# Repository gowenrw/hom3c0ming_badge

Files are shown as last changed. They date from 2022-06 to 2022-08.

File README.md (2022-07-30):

# hom3c0ming_badge

This is a DEFCON Indie badge created for D3FC0N HOM3C0MING a.k.a. DC30.

This is where all the files for the hom3c0ming Badge will be stored.

This includes code and art and cad and fab files.  All the things.

## File Structure

This is the file structure of this repository

* [/](/README.md) - YOU ARE HERE
* [/3D/](./3D/) - 3D print artifacts related to this project
* [/art/](./art/) - Artwork and other graphics created by this project
  * /art/inspiration/ - Art and graphics pulled from other sources used as inspiration for this project
* [/code/](./code/) - All project related Code / Firmware
  * /code/corsage/ - Code for the Raspberry Pi Pico on the corsage PCB
  * /code/firmware/ - CircuitPython firmware used by this project
* [/docs/](./docs/) - Documentation created by this project including web pages
* [/eda/](./eda/) - Electronic Design Automation files (i.e. KiCad)
  * /eda/hom3c0ming_boutonniere/ - KiCad project folder for the boutonniere PCB
  * /eda/hom3c0ming_corsage/ - KiCad project folder for the corsage PCB
* [/reference_parts/](./reference_parts/) - Documentation pulled from other sources related to components
* [./README.md](/README.md) - This File
* [./LICENSE](/LICENSE) - Currently set to MIT

Note: the reference_parts directory is a link to a submodule repository.
To add it use the following cmd after cloning this:
```
git submodule add https://github.com/gowenrw/reference_parts reference_parts
```
This will make a link to the current commit of that repo.
To update it to a newer commit after its been added use this cmd:
```
git submodule update --recursive
```

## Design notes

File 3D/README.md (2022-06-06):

# 3D

This is where all the 3D print artifacts for this project are located.

This project uses translucent 3D printed LED covers.

The LED covers are designed to be screwed to the PCB using M2 self threading screws (i.e.,  wood/machine screws, not bolts) via designated drill holes in the PCB.

## 3D STL Files

There is a 3D Model I created for the Rose shaped LED cover.
This has been provided in several STL files for printing (quantity differences supporting different print bed sizes or time constraints).

Here are the STL files:

*  [Rose_LED_Cover_w_Leaves.stl](Rose_LED_Cover_w_Leaves.stl)
*  [Rose_LED_Cover_w_Leaves_x15.stl](Rose_LED_Cover_w_Leaves_x15.stl)
*  [Rose_LED_Cover_w_Leaves_x20.stl](Rose_LED_Cover_w_Leaves_x20.stl)
*  [Rose_LED_Cover_w_Leaves_x40.stl](Rose_LED_Cover_w_Leaves_x40.stl)

## My Setup

I own a FlashForge Adventurer 3 printer which I slice prints for using FlashPrint, and a Creality Ender 3V2 which I slice prints for using Cura.

The directory FlashForgeAdv3 contains my FlashPrint project files, printer configuration profiles, and gcode for various STL files above.

The directory Ender3V2_Cura contains my Cura project files, printer configuration profiles, and gcode for various STL files above.

## Custom profile settings and material for this project

The material I am using for this project is the [Amazon Basics PLA 3D Printer Filament, 1.75mm, Translucent, 1 kg Spool](https://www.amazon.com/dp/B07SZLZG3L).

As you are setting up your machine to print these parts here are some notes about what I changed from my default print setting and why:

*  Layer height 0.16mm - Setting just a bit better than standard 0.2mm layers makes a big difference in the quality without that much added time.
*  Raft with 9mm-15mm margin - Given how small the surface area of the bottom layer is compared to the height, a wide solid raft was needed to prevent tip overs during printing

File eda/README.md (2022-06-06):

# Electronic Design Automation

This is where all the Electronic Design Automation files for the PCB(s) will be stored.
The EDA used is KiCad 5.x unless otherwise specified.

The KiCad projects have been configured to use local libraries for long term sustainability per the best practices listed [HERE](https://hackaday.com/2017/05/18/kicad-best-practises-library-management/) and elsewhere.

## File Structure

This is the file structure of this repository

* [/](/README.md) - Home
* [/eda](/eda/) - YOU ARE HERE
  * /eda/<eda_project>/ - KiCad project folder for the named project PCB(s)
    * ./3d_models/ - This directory contains footprint 3d model files
    * ./gerber/ - This directory contains gerber formatted files for manufacturing
    * ./lib_fp/ - This directory contains footprint module directories
    * ./lib_sh/ - This directory contains schematic library files
    * ./snapshots/ - This directory contains prints of schematic / cad files and images of preview / final product

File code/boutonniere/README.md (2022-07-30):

# Code

Code folder for the PCB.

Note: The boutonniere mini badge does not have a microcontroller and thus will have no code.

Keeping this directory in case I change my mind about that.

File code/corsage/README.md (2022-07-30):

# Code

Code folder for the PCB

Each directory here will contain the CircuitPython code and libraries to run the given program on the badge.

To change the code running on the badge simply connect the Pico via USB to a computer and replace the .py files and /lib files on the mass storage device with the ones provided in the chosen directory.

Note: If you upgrade the CircuitPython version you will need to download the version specific version of the library files to match the version you are running for any external libraries you are calling in your code (like neopixel.mpy).

You can download CircuitPython library files here:

[CircuitPython Library File Downloads](https://circuitpython.org/libraries)

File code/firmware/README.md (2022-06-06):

# Firmware

Firmware used by the badges

## Adafruit CircuitPython

I decided to use the Adafruit CircuitPython firmware on the Raspberry Pi Pico for the corsage badge.

Nothing against Raspberry MicroPython, I just like CircuitPython more.

The Raspberry Pi Pico boards that will be provided with the badges will be preloaded with a specific Adafruit CircuitPython version

Currently using version 7.2.5 but might change as we get closer to badge release date.

In case you need to reload your board or are using a different Pico than provided I have included the uf2 firmware file I used here so you can use the same version I did.

To load the new firmware follow these simple steps:

*  Push and hold the BOOTSEL button and plug your Pico into the USB port of your Raspberry Pi or other computer.
*  Release the BOOTSEL button after your Pico is connected.
*  It will mount as a Mass Storage Device called RPI-RP2
*  Drag and drop the CircuitPython UF2 file onto the RPI-RP2 volume.
*  Your Pico will reboot. You are now running CircuitPython.

If you wish to try a different version than I used then you can find all the CircuitPython for Pico downloads here:

[CircuitPython for Pico Downloads](https://circuitpython.org/board/raspberry_pi_pico/)

Note: If you upgrade the CircuitPython version you will need to download the version specific version of the library files to match the version you are running for any external libraries you are calling in your code (like neopixel.mpy).

You can download CircuitPython library files here:

[CircuitPython Library File Downloads](https://circuitpython.org/libraries)

For more information about the Raspberry Pi Pico including data sheets and downloads like their MicroPython firmware go to this page:

[Raspberry Pi Microcontrollers Documentation](https://www.raspberrypi.com/documentation/microcontrollers/)

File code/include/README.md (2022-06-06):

# Code Includes

Common code includes used by the other code folders

Since CircuitPython was chosen as the code base for the badge there will not be any include files.

Keeping this directory in case I change my mind about code base.

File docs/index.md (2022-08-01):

---
layout: default
---

[Home](/) - [Corsage](corsage-assembly.md) - [Boutonniere](boutonniere-assembly.md)

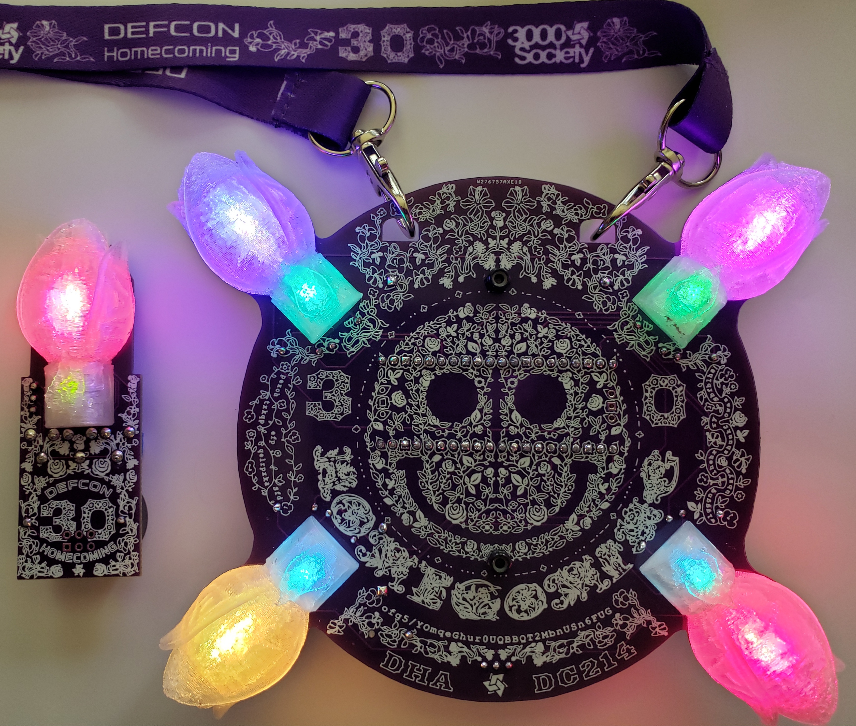
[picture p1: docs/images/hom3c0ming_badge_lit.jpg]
hom3c0ming badge


# hom3c0ming badge

Welcome to the hom3c0ming badge website/repository.

This is where you will find all the details and files and instructions related to my DC30 hom3c0ming badge kit.

The idea for this badge came from the DEFCON 30th anniversary theme: "Hacker Homecoming".
Thinking of the high school homecoming dances of my youth I immediately thought of flowers.

This kit is made up of two parts: A Corsage and a Boutonniere.
The corsage is the traditional badge shape/size with a lanyard and the boutonniere is a small pin-on or SAO attached add on.

I wanted to focus more on the art then features.  That being said, using the Raspberry Pi Pico opens up many hackable opportunities for this badge.
There are plenty of badges out there that do all the things.  I wanted this one to have all the looks.  And I think I have achieved that goal.

To focus on the art I spent literally hundreds of hours perfecting what is the most detailed silk layer I have ever attempted before.  I also included a 3D print element in the form of flowers that are LED diffusers which attach to the badge.

Regarding this being a kit that you need to assemble, this was a choice made due to popular demand.  My previous few badges were fully assembled and were big hits, but many people asked for kit versions and expressed their love of the DIY badge kit.  I think that building a badge from a kit gets a person invested in that badge and raises their appreciation for it.  So, the decision was made to make this a kit.

I hope that everyone who gets one of these badge kits enjoys it.  It was made with love for everyone in the community to enjoy.  And as with all my badges, it is all open hardware/software with all files provided in this repository.  So, if you didn't have a chance to get one of these kits at the con you can always make your own.

-- [@alt_bier](https://twitter.com/alt_bier)  - [My Contact Info](https://gowen.net/about)

---

# Details

Assembly Instructions for the Corsage can be found here: [Corsage](corsage-assembly.md)

Assembly Instructions for the Boutonniere can be found here: [Boutonniere](boutonniere-assembly.md)

Assembly walkthrough video can be found here:
[Hom3c0ming Badge Assembly](https://www.youtube.com/watch?v=d4AU95CxsSo&ab_channel=alt_bier_hacker)

More badge details to be added soon.

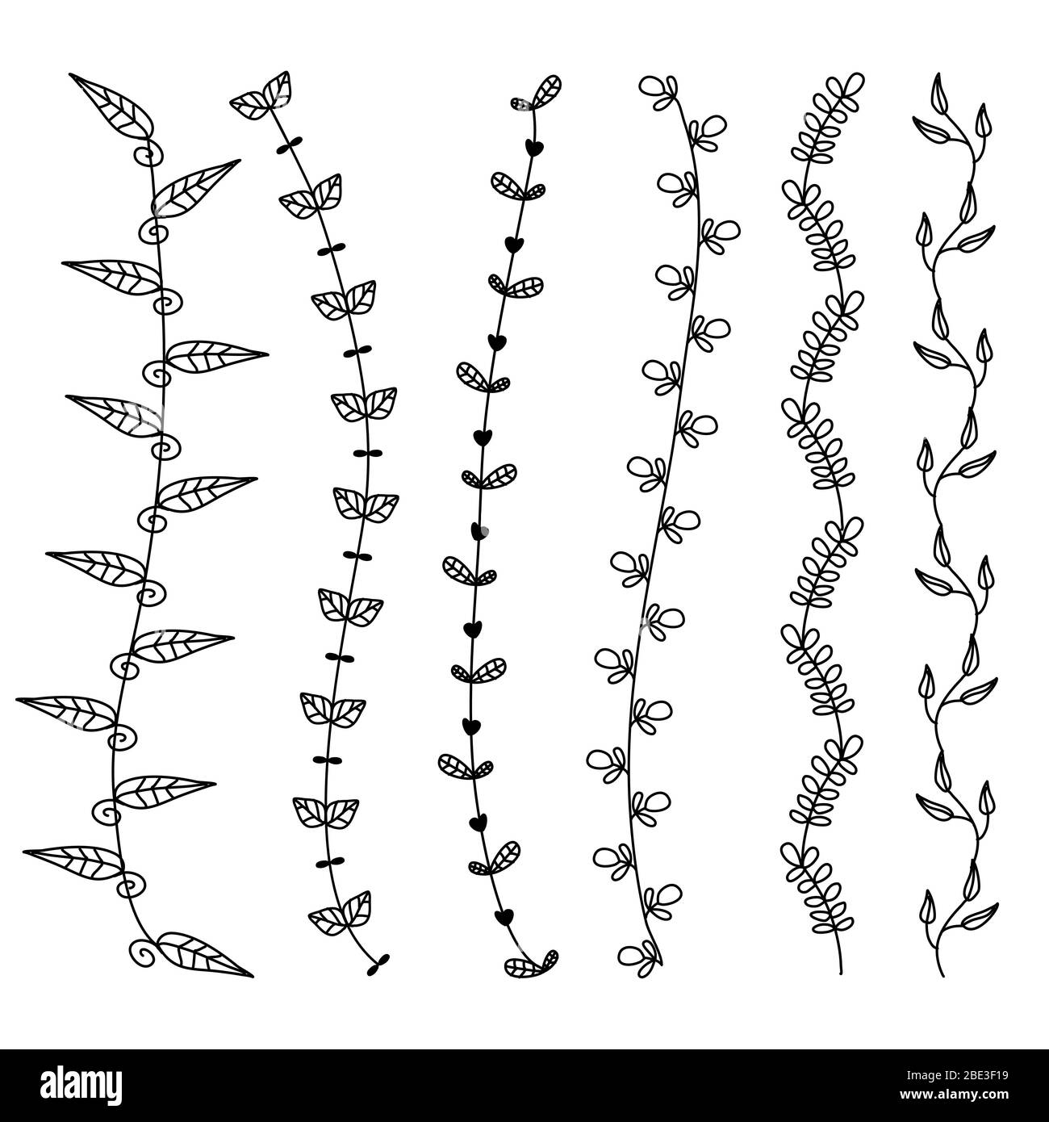
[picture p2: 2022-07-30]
art/inspiration/flower-vine-leaves-hand-drawn-doodle-vector-line-border-set-and-design-element-2BE3F19.jpg

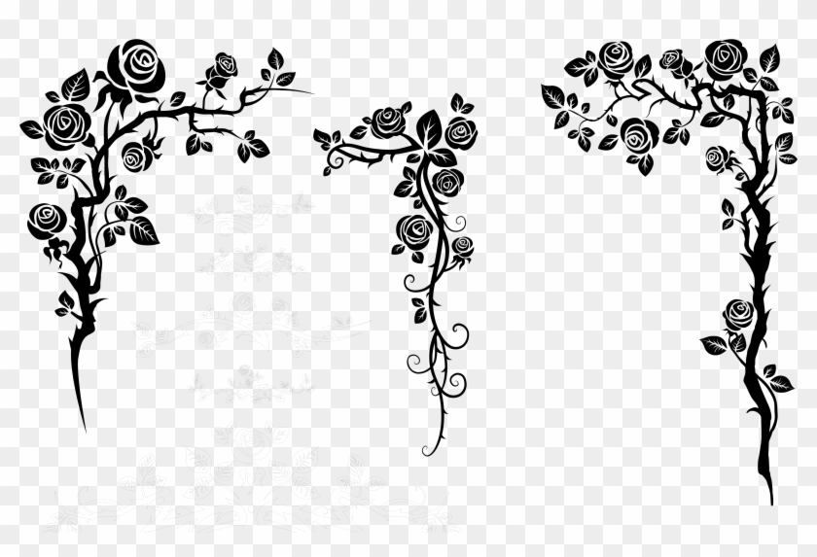
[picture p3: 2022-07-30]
art/inspiration/183-1831658_flower-vine-silhouette-nature-border-design-drawing-hd.png

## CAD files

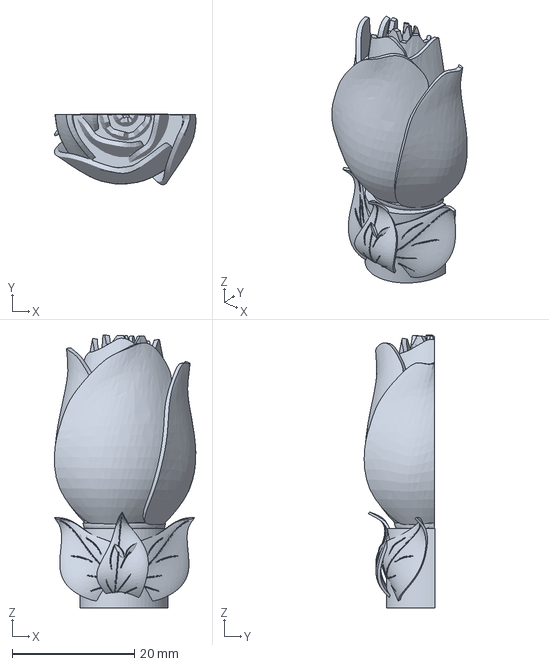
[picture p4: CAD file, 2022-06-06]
3D/Ender3V2_Cura/Rose_LED_Cover_w_Leaves.3mf
23.2 x 11.6 x 44.7 mm

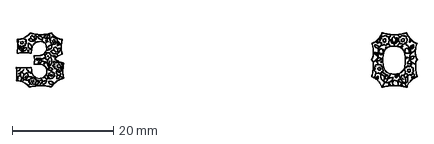
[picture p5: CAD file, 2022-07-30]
art/Corsage_front-2-Thirty.dxf
79.4 x 10.8 mm

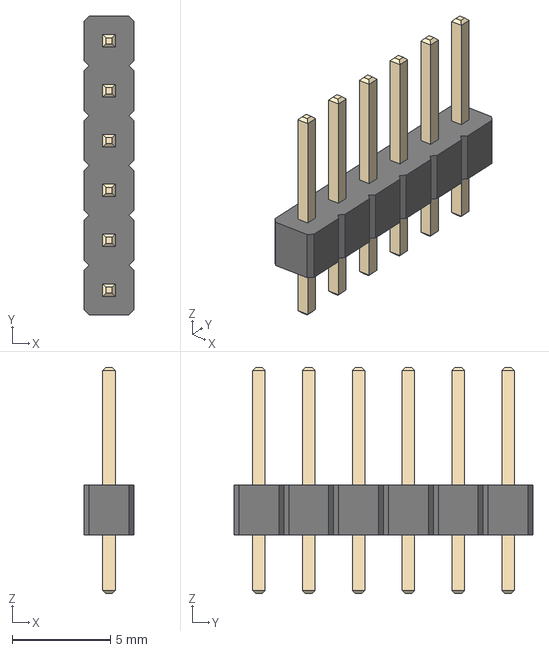
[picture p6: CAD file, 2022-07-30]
eda/hom3c0ming_boutonniere/3d_models/PinHeader_1x06_P2.54mm_Vertical.step
2.54 x 15.2 x 11.5 mm

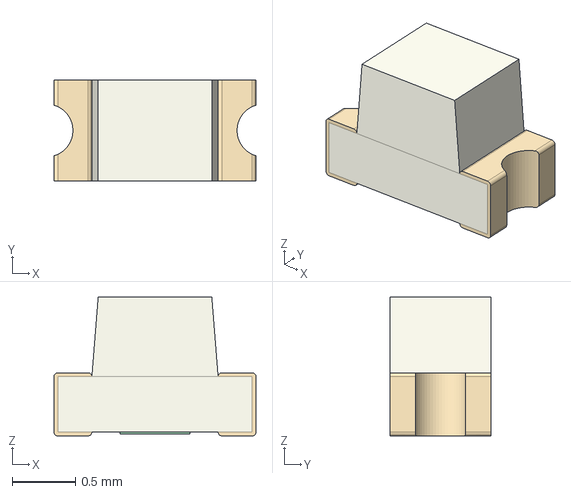
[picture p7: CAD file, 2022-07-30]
eda/hom3c0ming_corsage/3d_models/LED_0603_1608Metric_Castellated.step
1.60 x 0.8 x 1.10 mm

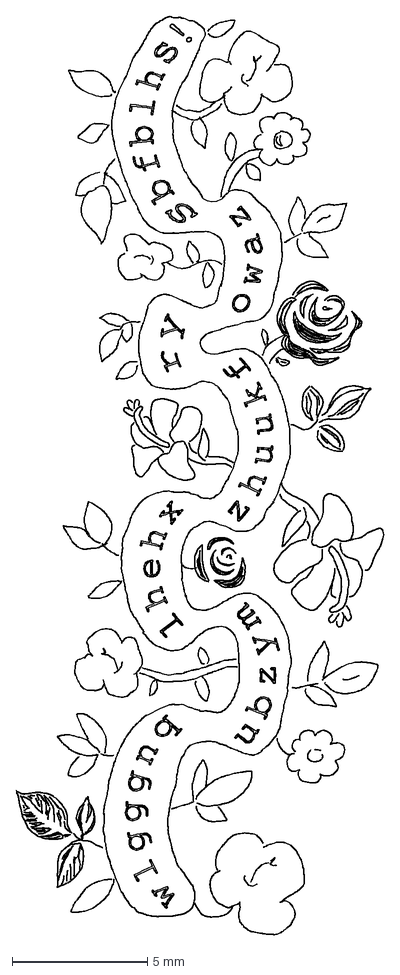
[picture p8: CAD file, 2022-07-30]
art/Corsage_front-4-FlowersRightSide.dxf
13.6 x 33.9 mm

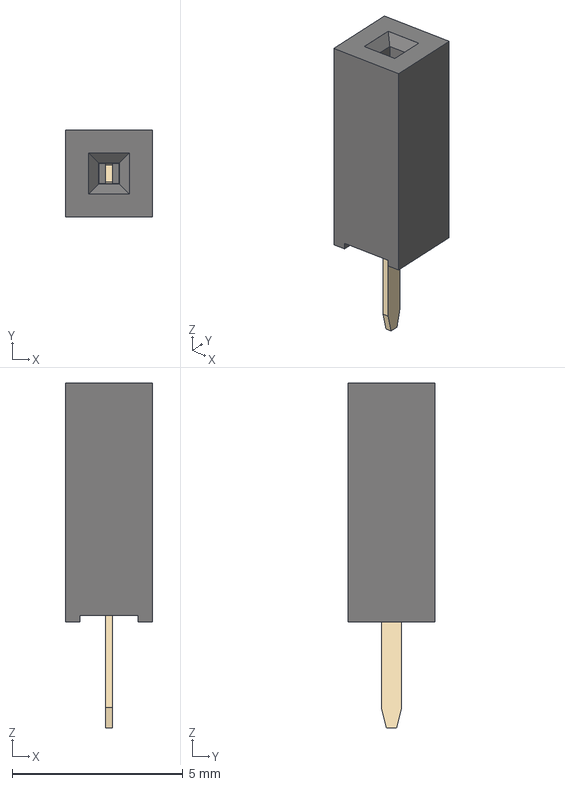
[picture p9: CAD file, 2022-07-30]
eda/hom3c0ming_boutonniere/3d_models/PinSocket_1x01_P2.54mm_Vertical.step
2.54 x 2.54 x 10.1 mm

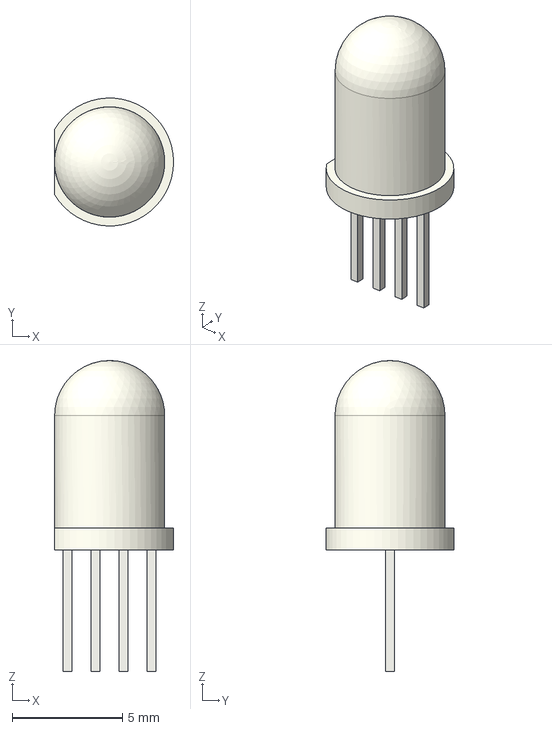
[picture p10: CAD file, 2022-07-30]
eda/hom3c0ming_corsage/3d_models/LED_D5.0mm-4_RGB_Neo.step
5.40 x 5.79 x 14.1 mm

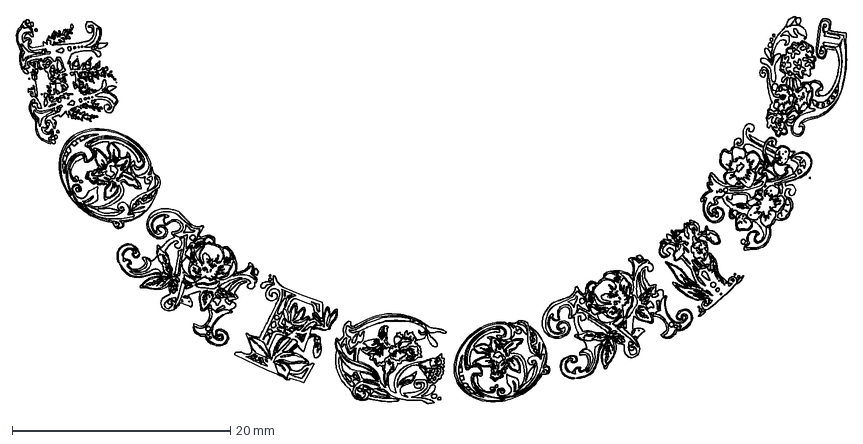
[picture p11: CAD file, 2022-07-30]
art/Corsage_front-2-HomeComing.dxf
76.0 x 35.5 mm

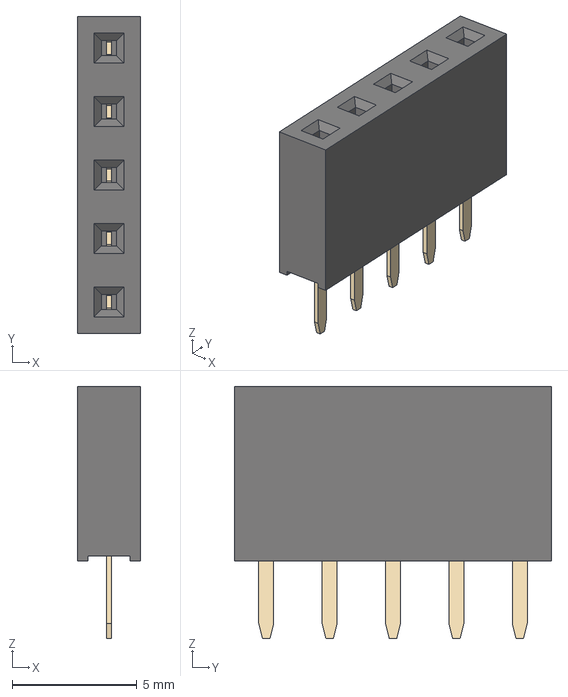
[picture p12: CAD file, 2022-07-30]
eda/hom3c0ming_boutonniere/3d_models/PinSocket_1x05_P2.54mm_Vertical.step
2.54 x 12.7 x 10.1 mm

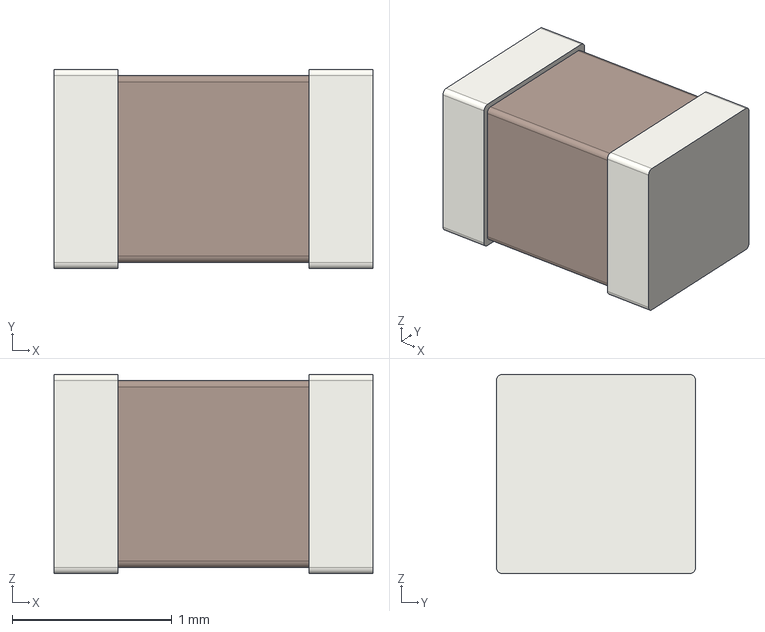
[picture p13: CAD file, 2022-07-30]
eda/hom3c0ming_corsage/3d_models/C_0805_2012Metric.step
2.00 x 1.25 x 1.25 mm

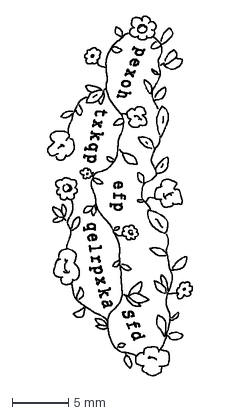
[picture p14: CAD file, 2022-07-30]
art/Corsage_front-4-FlowersLeftSide.dxf
12.9 x 31.9 mm

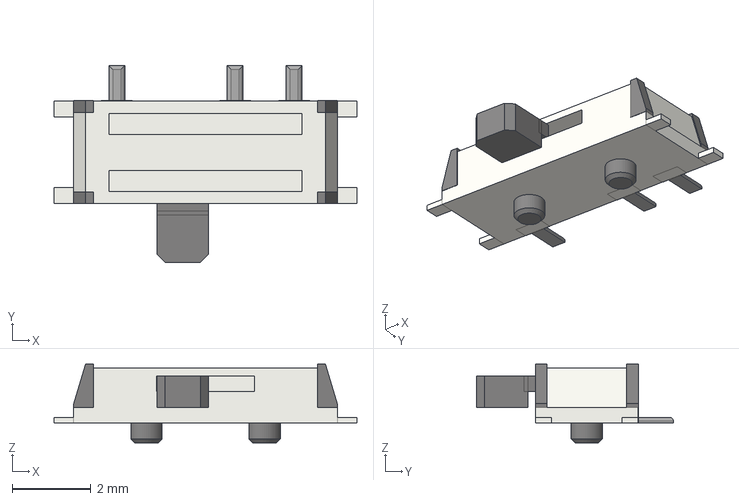
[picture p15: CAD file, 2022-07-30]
eda/hom3c0ming_boutonniere/3d_models/SW_SPDT_PCM12.step
7.70 x 5.00 x 2.00 mm

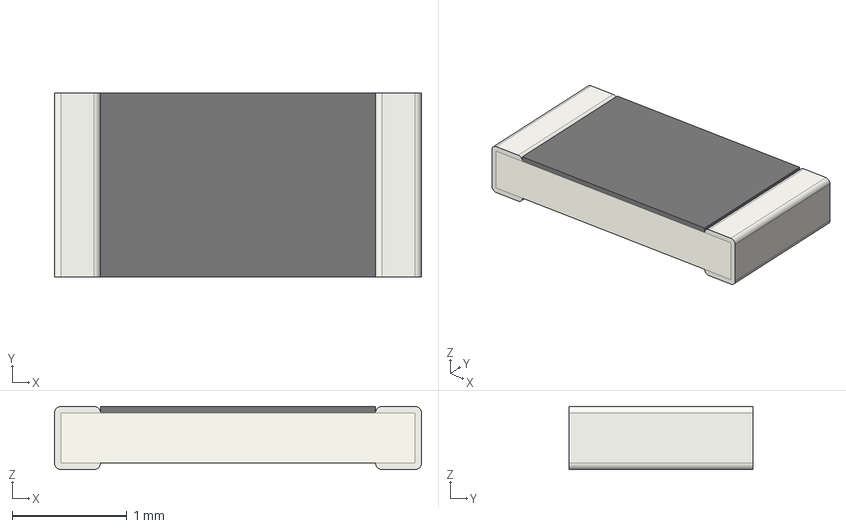
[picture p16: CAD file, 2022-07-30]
eda/hom3c0ming_corsage/3d_models/R_1206_3216Metric.step
3.20 x 1.60 x 0.55 mm

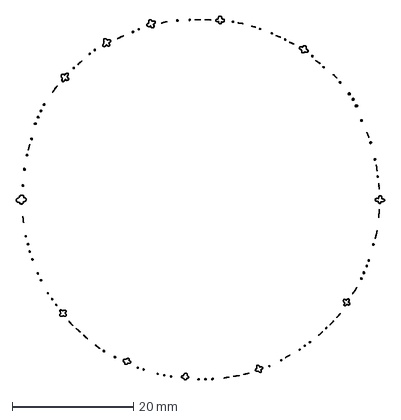
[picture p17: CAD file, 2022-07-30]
art/Corsage_front-3-MLine.dxf
60.7 x 59.9 mm

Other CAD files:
3D/Rose_LED_Cover_w_Leaves.stl
eda/hom3c0ming_boutonniere/3d_models/PinHeader_1x08_P2.54mm_Horizontal.step
eda/hom3c0ming_corsage/3d_models/C_Rect_L4.6mm_W2.0mm_P2.50mm_MKS02_FKP02.step
art/Corsage_front-5-FlowersBottom.dxf
eda/hom3c0ming_boutonniere/3d_models/BatteryHolder_2466_1xAAA.step
eda/hom3c0ming_boutonniere/3d_models/BatteryHolder_2468_2xAAA.step
eda/hom3c0ming_boutonniere/3d_models/Battery_Holder_3xAAA_Simple.step
eda/hom3c0ming_boutonniere/3d_models/Battery_Holder_CR2032_BS-2-1.stp
eda/hom3c0ming_boutonniere/3d_models/CP_Radial_D5.0mm_P2.00mm.step
eda/hom3c0ming_boutonniere/3d_models/CP_Radial_D6.3mm_P2.50mm.step
eda/hom3c0ming_boutonniere/3d_models/C_0603_1608Metric.step
eda/hom3c0ming_boutonniere/3d_models/C_1206_3216Metric.step
eda/hom3c0ming_boutonniere/3d_models/C_Disc_D3.0mm_W2.0mm_P2.50mm.step
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

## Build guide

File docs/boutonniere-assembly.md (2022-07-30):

---
layout: default
---

[Home](/) - [Corsage](corsage-assembly.md) - [Boutonniere](boutonniere-assembly.md)

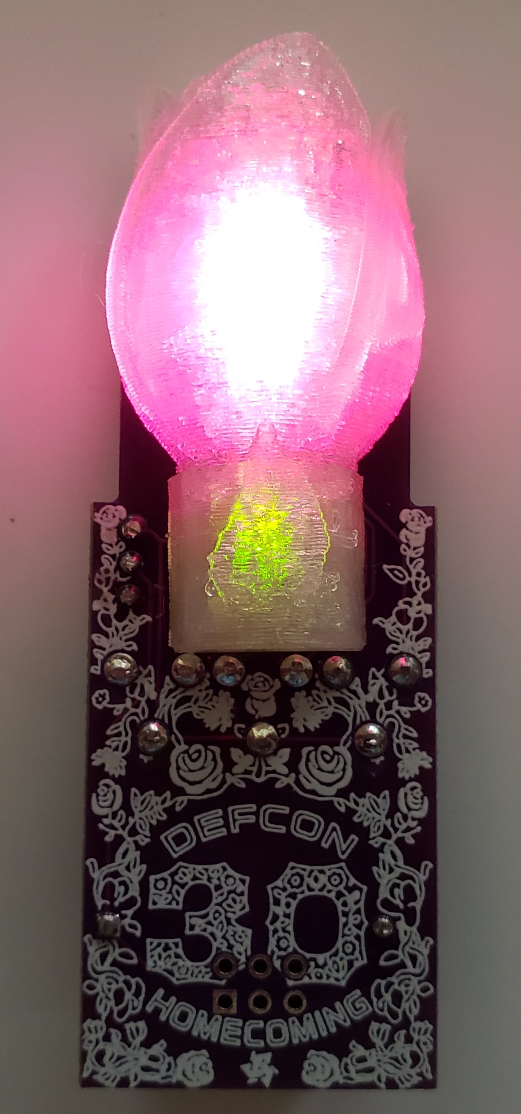
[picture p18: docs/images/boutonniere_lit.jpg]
Boutonniere Image


# Boutonniere Assembly Instructions

Here are the assembly instructions I put together for the Boutonniere hom3c0ming badge add on.

## Component List

This is the list of components that you should have available for the assembly.

*  Boutonniere Kit Bag
    *  1x PCB
    *  1x CR2032 Battery Holder
    *  1x CR2032 Battery
    *  1x 3D Printed Flower LED Diffusers
    *  Boutonniere Small Component Bag Containing:
        *  1x SS12D00 3-Pin SPDT Switch
        *  1x 100 Ohm Resistor
        *  1x 220 Ohm Resistor
        *  3x 47 Ohm Resistors
        *  3x 0-10K Ohm 3-Pin Variable Resistors
        *  1x RGB Common Cathode 5mm 4-Pin LED
        *  1x Green 3mm 2-Pin LED
        *  1x Broach Clip 20mm
        *  Small Screw Hardware Bag Containing:
            *  2x M2x6 Phillips Pan Head Self Tapping Screws
            *  2x M2x5 Phillips Pan Head Screws
            *  2x M2 Hex Nuts

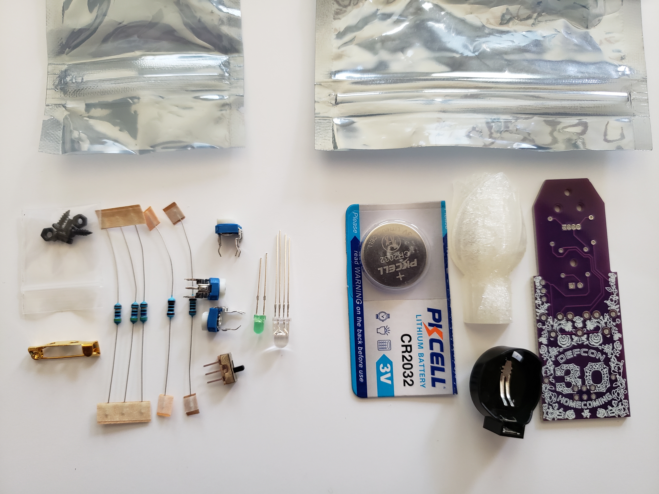
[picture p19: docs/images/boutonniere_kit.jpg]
Boutonniere Kit


## Soldering Steps

These are the assembly steps that require soldering.
I have presented them in the order I recommend they be implemented for best results.

Before soldering you will need to make a choice between the 100 ohm and 220 ohm resistors for use with the 3mm green LED.  The lower resistance will make the green LED slightly brighter.  I personally prefer the look with the 220 ohm resistor.

*  Solder the 3x 47 Ohm Resistors to the back side of the PCB using the THT holes labeled R1, R2, R3.
    *  This component should be placed with its body on the back side of the PCB and its pins sticking through to the front side of the PCB.
    *  Bending the component pins to an angle after insertion into the PCB will keep it in place when flipping over the PCB to solder.
    *  The component pins should be soldered on the front side of the PCB.
    *  The component pins should be cut as flush to the PCB as the solder joint allows (don't cut the solder joint!).

*  Solder either the 100 ohm OR the 220 ohm Resistor to the back side of the PCB using the THT holes labeled R4.
    *  This component should be placed with its body on the back side of the PCB and its pins sticking through to the front side of the PCB.
    *  Bending the component pins to an angle after insertion into the PCB will keep it in place when flipping over the PCB to solder.
    *  The component pins should be soldered on the front side of the PCB.
    *  The component pins should be cut as flush to the PCB as the solder joint allows (don't cut the solder joint!).

*  Solder the 1x RGB Common Cathode 5mm 4-Pin LED to the front side of the PCB using the THT holes labeled D1.
    *  This component should be placed with its body on the front side of the PCB and its pins sticking through to the back side of the PCB.
    *  Take care to ensure that the component is inserted with the correct alignment by comparing the flat side of the LED body to the indicator lines on the PCB.
    *  This component should be fully inserted in the PCB as far as it can go (i.e., past the stop notches on the pins)
    *  Take care to ensure the component body stays flush to the PCB at 90 degrees when soldering (which should not be much of an issue if inserted fully)
    *  The component pins should be soldered on the back side of the PCB.
    *  The component pins should be cut as flush to the PCB as the solder joint allows (don't cut the solder joint!).

*  Solder the 1x Green 3mm 2-Pin LED to the front side of the PCB using the THT holes labeled D2.
    *  This component should be placed with its body on the front side of the PCB and its pins sticking through to the back side of the PCB.
    *  Take care to ensure that the component is inserted with the correct alignment by comparing the flat side of the LED body to the indicator lines on the PCB.
    *  This component should be fully inserted in the PCB as far as it can go (i.e., past the stop notches on the pins)
    *  Take care to ensure the component body stays flush to the PCB at 90 degrees when soldering (which should not be much of an issue if inserted fully)
    *  The component pins should be soldered on the back side of the PCB.
    *  The component pins should be cut as flush to the PCB as the solder joint allows (don't cut the solder joint!).

*  Solder the 3-Pin Switch to the back side of the PCB using the THT holes labeled ON / OFF.
    *  This component should be placed with its body on the back side of the PCB and its pins sticking through to the front side of the PCB.
    *  Take care to ensure the component body stays flush to the PCB at 90 degrees when soldering
    *  The component pins should be soldered on the front side of the PCB.
    *  The component pins should be cut as flush to the PCB as the solder joint allows (don't cut the solder joint!).  

*  Solder the 3x 0-10K Ohm 3-Pin Variable Resistors to the back side of the PCB using the THT holes labeled RV1, RV2, RV3.
    *  This component should be placed with its body on the back side of the PCB and its pins sticking through to the front side of the PCB.
    *  Take care to ensure that the component is inserted with the correct alignment by using the indicator lines on the PCB.
    *  The component pins should be soldered on the front side of the PCB.
    *  The component pins should be cut as flush to the PCB as the solder joint allows (don't cut the solder joint!).
    *  Pro Tip: Inserting all of these components and then soldering them all allows for faster assembly time

*  Solder the CR2032 Battery Holder to the back side of the PCB in the area indicated on the PCB
    *  This component should be placed with its body on the back side of the PCB and its pins sticking through to the front side of the PCB.
    *  Take care to ensure that the component is inserted with the correct alignment by using the indicator lines on the PCB.
    *  The component pins should be soldered on the front side of the PCB.
    *  The component pins should be cut as flush to the PCB as the solder joint allows (don't cut the solder joint!).
    * Note: If you plan on soldering an SAO connector (not provided in the kit) to this badge then you must NOT solder this battery connector on as this is an either or choice.

## Additional Assembly Steps

These are the additional assembly steps that do not require soldering.
I have presented them in the order I recommend they be implemented for best results.

*  Attach the Broach Clip to the back of the PCB using the M2 fasteners
    *  Unclip the Broach Clip pin and move the pin out of the way exposing the attachment holes.
    *  Hold the Broach Clip against the back of the PCB in its designated location as marked on the PCB making sure the attachment holes line up with the drill holes on the PCB.
    *  Insert an M2x2 Phillips Pan Head Screw through one of the Broach Clip attachment holes into the back of the PCB
    *  Hold the M2 screw in place using a small Phillips head screwdriver
    *  While holding the screw and Broach Clip in place attach an M2 Hex Nut to the end of the screw on the front of the PCB and use fingers to rotate the nut until it is close to the PCB but still loose
    *  Insert an M2x2 Phillips Pan Head Screw through the other Broach Clip attachment hole into the back of the PCB
    *  Hold the M2 screw in place using a small Phillips head screwdriver
    *  While holding the screw and Broach Clip in place attach an M2 Hex Nut to the end of the screw on the front of the PCB and use fingers to rotate the nut until it is close to the PCB but still loose
    *  While holding the hex nuts in place with a tool or fingers, tighten each of these fasteners with a small Phillips head screwdriver
    *  Close the pin on the Broach Clip

*  Attach the 3D Printed Flower LED Diffuser to the front of the PCB using the M2 fasteners
    *  Insert an M2x6 Phillips Pan Head Self Tapping Screw into the back of the PCB into the bottom of the two PCB holes for a flower
    *  Hold the M2 screw in place using a small Phillips head screwdriver
    *  Align the flower middle screw hole over the M2 screw tip sticking through the PCB
    *  While holding the flower in place in the correct alignment (flower top towards PCB edge) use a small Phillips head screwdriver to tighten this fastener just enough that it has a solid grip on the flower but the flower can still move around - DO NOT FULLY TIGHTEN YET
    *  Insert an M2x6 Phillips Pan Head Self Tapping Screw into the back of the PCB into the top (PCB edge) of the two PCB holes for a flower
    *  Hold the M2 screw in place using a small Phillips head screwdriver
    *  Align the flower top screw hole over the M2 screw tip sticking through the PCB
    *  While holding the flower in place in the correct alignment use a small Phillips head screwdriver to fully tighten this fastener in place
    *  Use a small Phillips head screwdriver to fully tighten the bottom screw in place which was left loose in the previous step

## Battery, Pin, and Wear FTW

*  Insert the CR2032 battery into the battery holder with the Positive (+) side up and visible.
    *  Take care to insert using proper polarity or the badge will not power on.

*  Attach the badge to clothing or items by pinning in place using the Broach Clip.

*  With the battery inserted and the badge attached, the ON/OFF switch will control your #Badgelife awesomeness factor

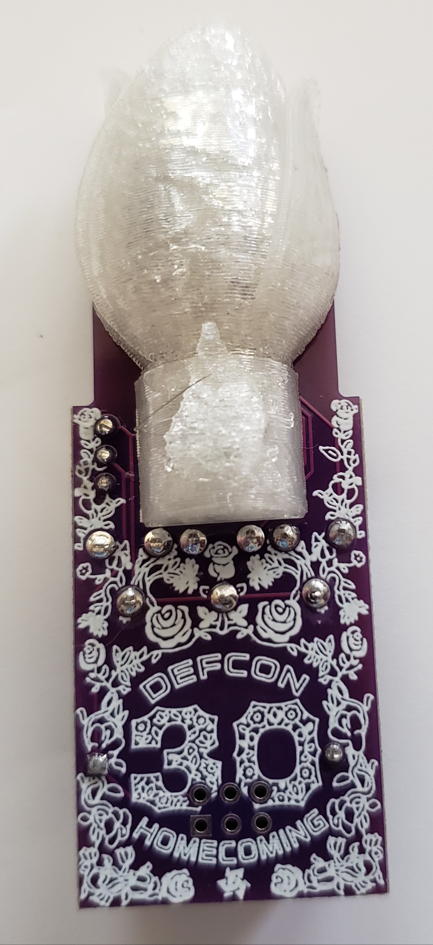
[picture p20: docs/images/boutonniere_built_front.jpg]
Boutonniere Front


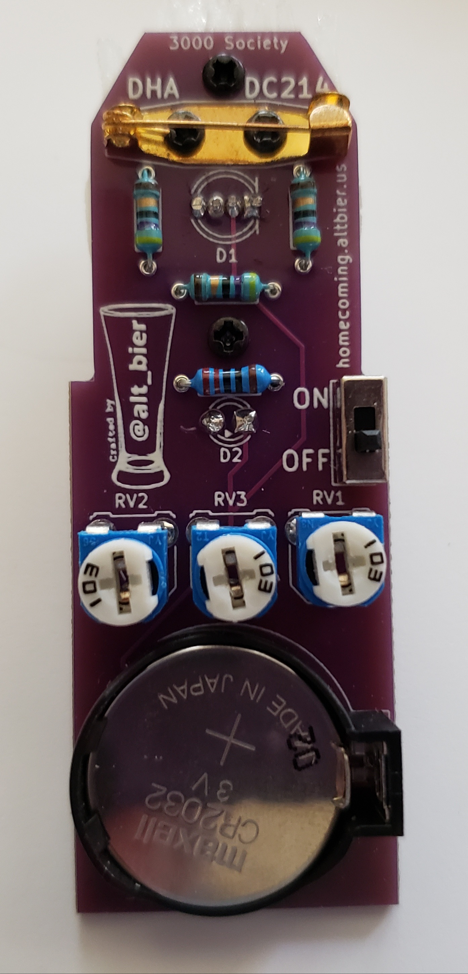
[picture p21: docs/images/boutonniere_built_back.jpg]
Boutonniere Back


-- [@alt_bier](https://twitter.com/alt_bier)  - [My Contact Info](https://gowen.net/about)

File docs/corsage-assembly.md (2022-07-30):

---
layout: default
---

[Home](/) - [Corsage](corsage-assembly.md) - [Boutonniere](boutonniere-assembly.md)

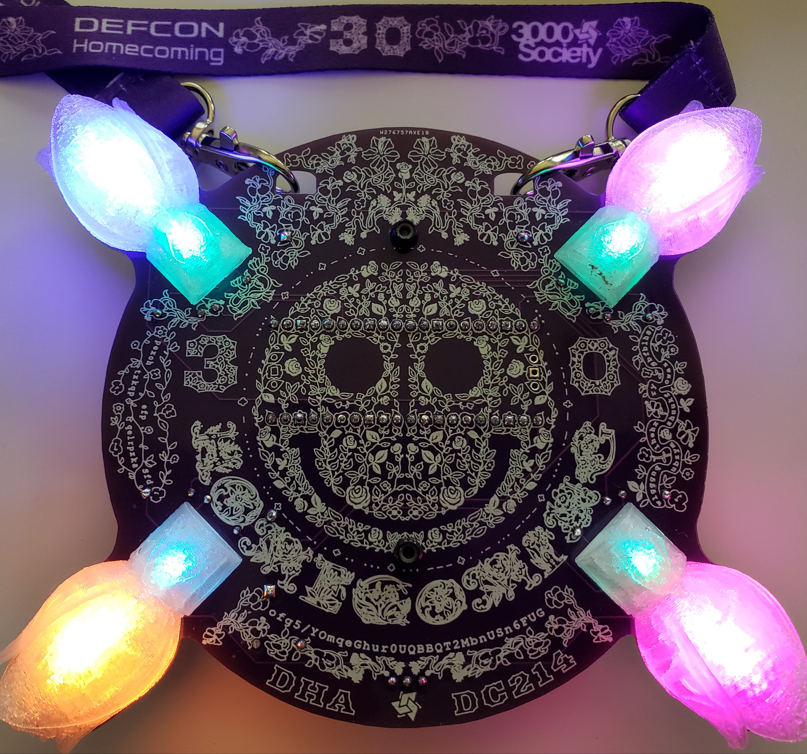
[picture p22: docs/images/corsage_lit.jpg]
Corsage Image


# Corsage Assembly Instructions

Here are the assembly instructions I put together for the Corsage hom3c0ming badge.

## Component List

This is the list of components that you should have available for the assembly.

*  Main Kit Bag Containing:
    *  1x Sticker (Not Required for Corsage Assembly)
    *  1x PCB
    *  1x Lanyand
    *  3x AAA Batteries
    *  Boutonniere Kit Bag (Not Required for Corsage Assembly)
    *  Corsage Large Component Bag Containing:
        *  1x Raspberry Pi Pico
        *  1x Header Pin Breakaway Strip with 1x40 Pins  
        *  1x Single AAA Battery Holder with THT Pins
        *  1x Dual AAA Battery Holder with THT Pins
        *  4x 3D Printed Flower LED Diffusers
        *  1x Mini Phillips Head Screwdriver
        *  Small Screw Hardware Bag Containing:
            *  8x M2x6 Phillips Pan Head Self Tapping Screws
            *  2x M2.5x6 Phillips Flat Head Screws
            *  2x M2.5 Nylock Hex Locking Nuts
  *  Corsage Small Component Bag Containing:
      *  1x CJ3415 SMT PNP MOSFET Transistor
      *  1x SS12D00 3-Pin SPDT Switch
      *  1x 22K Ohm Resistor
      *  12x 470 Ohm Resistors
      *  4x 100nF Ceramic Disc Capacitors
      *  4x WS2812D RPIN 5mm 4-Pin Addressable LEDs
      *  4x Two Color (BG) 3mm 3-Pin LEDs

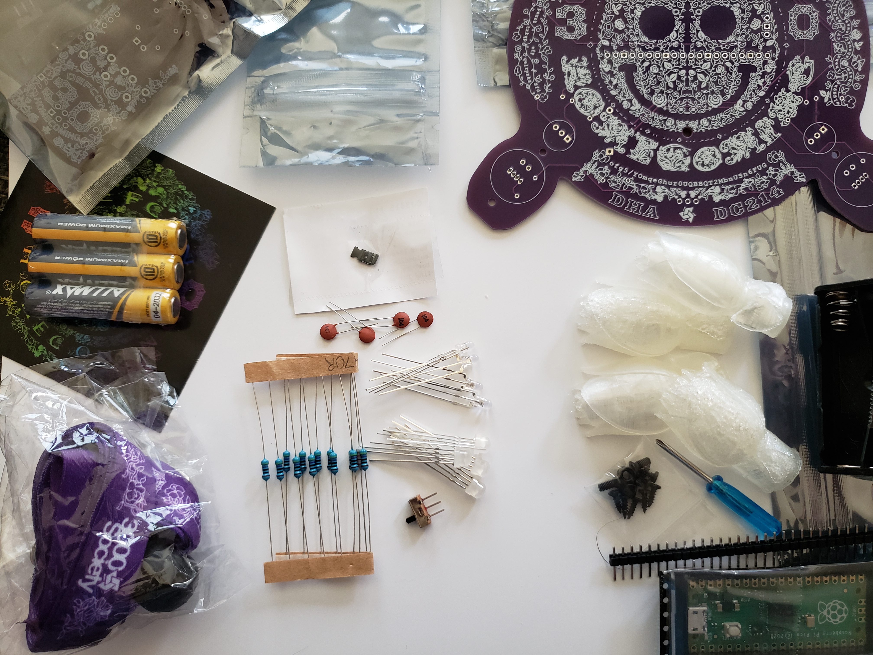
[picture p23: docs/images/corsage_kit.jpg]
Corsage Kit


## Soldering Steps

These are the assembly steps that require soldering.
I have presented them in the order I recommend they be implemented for best results.

### Power Protection Circuit

*  Solder the SMT MOSFET Transistor to the back side of the PCB on the pads labeled Q1.
    *  This is a surface mount component that can be hand soldered to the PCB
    *  The PCB pads for this component are extra wide to assist in hand soldering
    *  Solder the component to the back side of the PCB.
        *  The component will need to be held in place until the first pin is soldered (use a tool not a thumbnail!)

*  Solder the 22K Ohm Resistor to the back side of the PCB using the THT holes labeled R1.
    *  This component should be placed with its body on the back side of the PCB and its pins sticking through to the front side of the PCB.
    *  Bending the component pins to an angle after insertion into the PCB will keep it in place when flipping over the PCB to solder.
    *  The component pins should be soldered on the front side of the PCB.
    *  The component pins should be cut as flush to the PCB as the solder joint allows (don't cut the solder joint!).

*  Solder the 3-Pin Switch to the back side of the PCB using the THT holes labeled ON / OFF.
    *  This component should be placed with its body on the back side of the PCB and its pins sticking through to the front side of the PCB.
    *  Take care to ensure the component body stays flush to the PCB at 90 degrees when soldering
    *  The component pins should be soldered on the front side of the PCB.
    *  The component pins should be cut as flush to the PCB as the solder joint allows (don't cut the solder joint!).  

### Small Back Side Components: Resistors

*  Solder the 12x 470 Ohm Resistors to the back side of the PCB using the THT holes labeled R2, R4, R6, R8, R10, R12, R14, R16, R181, R182, R201, R202.
    *  This component should be placed with its body on the back side of the PCB and its pins sticking through to the front side of the PCB.
    *  Bending the component pins to an angle after insertion into the PCB will keep it in place when flipping over the PCB to solder.
    *  The component pins should be soldered on the front side of the PCB.
    *  The component pins should be cut as flush to the PCB as the solder joint allows (don't cut the solder joint!).
    *  Pro Tip: Inserting all of these components and then soldering them all allows for faster assembly time

### Small Front Side Components: LEDs and Capacitors

*  Solder the 4x Two Color 3mm 3-Pin LEDs to the front side of the PCB using the THT holes labeled D1, D2, D3, D4.
    *  This component should be placed with its body on the front side of the PCB and its pins sticking through to the back side of the PCB.
    *  Take care to ensure that the component is inserted with the correct alignment by comparing the flat side of the LED body to the indicator lines on the PCB.
    *  This component should be fully inserted in the PCB as far as it can go (i.e., past the stop notches on the pins)
    *  Take care to ensure the component body stays flush to the PCB at 90 degrees when soldering (which should not be much of an issue if inserted fully)
    *  The component pins should be soldered on the back side of the PCB.
    *  The component pins should be cut as flush to the PCB as the solder joint allows (don't cut the solder joint!).
    *  Pro Tip: Inserting all of these components and then soldering them all allows for faster assembly time and keeps the PCB level while soldering.

*  Solder the 4x 100nF Ceramic Disc Capacitors to the front side of the PCB using the THT holes labeled C501, C502, C601, C602.
    *  This component should be placed with its body on the front side of the PCB and its pins sticking through to the back side of the PCB.
    *  Bending the component pins to an angle after insertion into the PCB will keep it in place when flipping over the PCB to solder.
    *  The component pins should be soldered on the back side of the PCB.
    *  The component pins should be cut as flush to the PCB as the solder joint allows (don't cut the solder joint!).
    *  Pro Tip: Inserting all of these components and then soldering them all allows for faster assembly time

*  Solder the 4x WS2812D 5mm 4-Pin LEDs to the front side of the PCB using the THT holes labeled D501, D502, D601, D602.
    *  This component should be placed with its body on the front side of the PCB and its pins sticking through to the back side of the PCB.
    *  Take care to ensure that the component is inserted with the correct alignment by comparing the flat side of the LED body to the indicator lines on the PCB.
    *  This component should be fully inserted in the PCB as far as it can go (i.e., past the stop notches on the pins)
    *  Take care to ensure the component body stays flush to the PCB at 90 degrees when soldering (which should not be much of an issue if inserted fully)
    *  The component pins should be soldered on the back side of the PCB.
    *  The component pins should be cut as flush to the PCB as the solder joint allows (don't cut the solder joint!).
    *  Pro Tip: Inserting all of these components and then soldering them all allows for faster assembly time and keeps the PCB level while soldering.

### Raspberry Pi Pico

*  Solder the header pins onto the Raspberry Pi Pico board
    *  Break the 1x40 Pin Header Pin Breakaway Strip into two 1x20 strips
    *  Insert the 1x20 header pin strips into the THT holes on each side of the Pico board
        *  The header pins should be inserted opposite of normal, inserting the long pin side poking through the top of the Pico board leaving the short pin side for soldering to the PCB. This has two advantages:
            *  This Avoids the need to cut the header pins on the front of the PCB.
            *  This allows the possibility of connecting external things to the Pico using female jumper wires on the back of the PCB.
    *  Take care to ensure the header pins stay flush to the Pico board at 90 degrees when soldering
        *  This can be easily accomplished by placing on a breadboard
    *  The header pins should be soldered on the top side of the Pico
    *  Optionally the header pins can be cut flush to the top of the Pico board (leave as is if you wish have the option to connect to the Pico pins using jumper wires)

*  Solder the Pico board to the back of the PCB using the THT holes labeled IC1
    *  The Pico should be placed with its body on the back side of the PCB (with the top of the Pico visible) and its header pins sticking through to the front side of the PCB.
    *  Take care to ensure that the Pico is inserted with the correct alignment by comparing the three holes on short side of the Pico with the same holes on the PCB.
    *  The Pico header pins should be soldered on the front side of the PCB.
    *  If the header pins were attached to the Pico with the short legs down then there should be no need to cut the pins flush on the front of the PCB.

### Battery Holders

*  Solder the Dual AAA Battery Holder to the back side of the PCB in the area indicated on the PCB
    *  This component should be placed with its body on the back side of the PCB and its pins sticking through to the front side of the PCB.
    *  The component pins should be soldered on the front side of the PCB.
    *  The component pins should be cut as flush to the PCB as the solder joint allows (don't cut the solder joint!).

*  Solder the Single AAA Battery Holder to the back side of the PCB in the area indicated on the PCB
    *  This component should be placed with its body on the back side of the PCB and its pins sticking through to the front side of the PCB.
    *  Take care to ensure that the component is inserted with the correct alignment by comparing the pin polarity of the component with the polarity markings on the PCB
    *  The component pins should be soldered on the front side of the PCB.
    *  The component pins should be cut as flush to the PCB as the solder joint allows (don't cut the solder joint!).

## Additional Assembly Steps

These are the additional assembly steps that do not require soldering.
I have presented them in the order I recommend they be implemented for best results.

### Secure Battery Holders to PCB

*  Attach each Battery Holder Securely to the back of the PCB using the M2.5 fasteners
    *  Insert an M2.5x6 Phillips Flat Head Screw into the back of the PCB through the hole in the middle of the battery holder
    *  Hold the M2.5 screw in place using a small Phillips head screwdriver
    *  Attach the M2.5 Nylock hex nut onto the M2.5 Screw on the front of the PCB
    *  While holding the Nylock nut in place use a small Phillips head screwdriver to tighten this fastener in place
    *  Repeat the above steps for the other battery holder.

### Attach 3D Printed Flowers to PCB

*  Attach each 3D Printed Flower LED Diffuser to the front of the PCB using the M2 fasteners
    *  Insert an M2x6 Phillips Pan Head Self Tapping Screw into the back of the PCB into the bottom of the two PCB holes for a flower
    *  Hold the M2 screw in place using a small Phillips head screwdriver
    *  Align the flower middle screw hole over the M2 screw tip sticking through the PCB
    *  While holding the flower in place in the correct alignment (flower top towards PCB edge) use a small Phillips head screwdriver to tighten this fastener just enough that it has a solid grip on the flower but the flower can still move around - DO NOT FULLY TIGHTEN YET
    *  Insert an M2x6 Phillips Pan Head Self Tapping Screw into the back of the PCB into the top (PCB edge) of the two PCB holes for a flower
    *  Hold the M2 screw in place using a small Phillips head screwdriver
    *  Align the flower top screw hole over the M2 screw tip sticking through the PCB
    *  While holding the flower in place in the correct alignment use a small Phillips head screwdriver to fully tighten this fastener in place
    *  Use a small Phillips head screwdriver to fully tighten the bottom screw in place which was left loose in the previous step
    *  Repeat the above steps for each of the four 3D printed flowers.

## Batteries, Lanyard, and Wear FTW

*  Insert the three AAA batteries into the battery holders.
    *  Take care to insert using proper polarity or the badge will not power on.

*  Attach the Lanyard to the PCB using the two lanyard clips in the two top arched holes in the PCB.
    *  The lanyard has a length adjustment attachment that can be moved as needed using its button

*  With the batteries inserted and the badge around your neck, the ON/OFF switch will control your #Badgelife awesomeness factor
    *  The badge should be turned off when connecting to the Pico using its USB cable (although the power protection circuit should prevent the blue smoke monster)

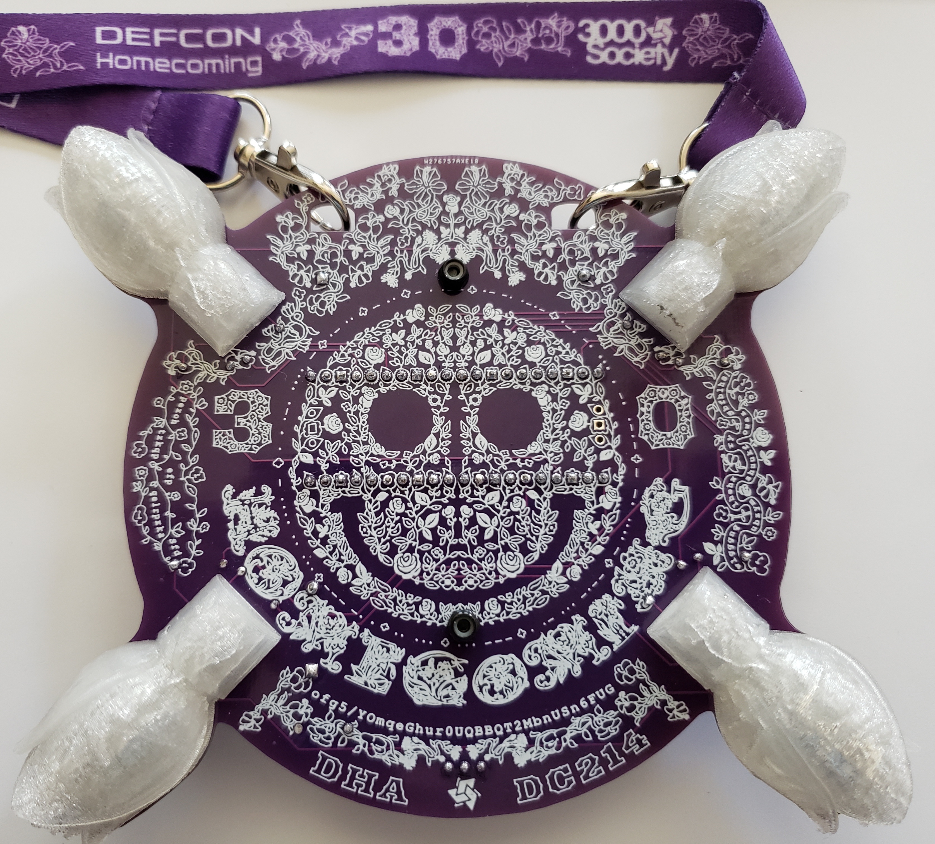
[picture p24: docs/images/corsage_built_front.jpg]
Corsage Front


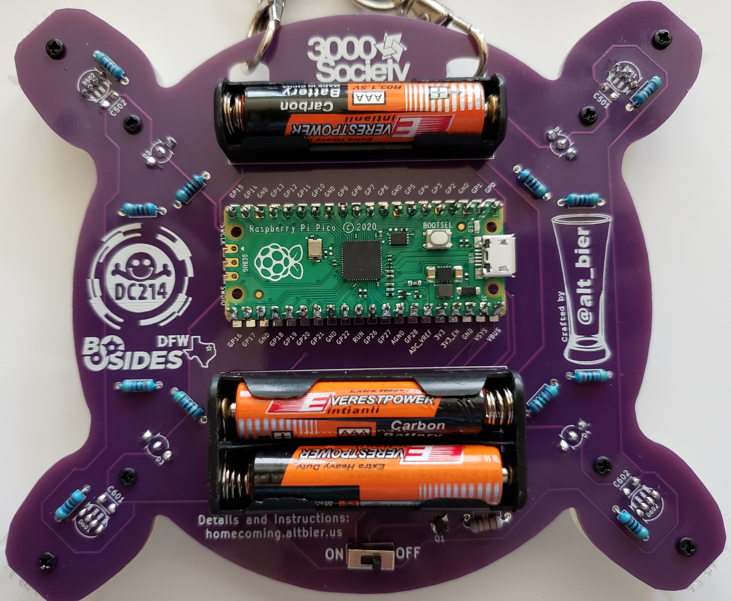
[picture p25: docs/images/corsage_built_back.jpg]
Corsage Back


-- [@alt_bier](https://twitter.com/alt_bier)  - [My Contact Info](https://gowen.net/about)

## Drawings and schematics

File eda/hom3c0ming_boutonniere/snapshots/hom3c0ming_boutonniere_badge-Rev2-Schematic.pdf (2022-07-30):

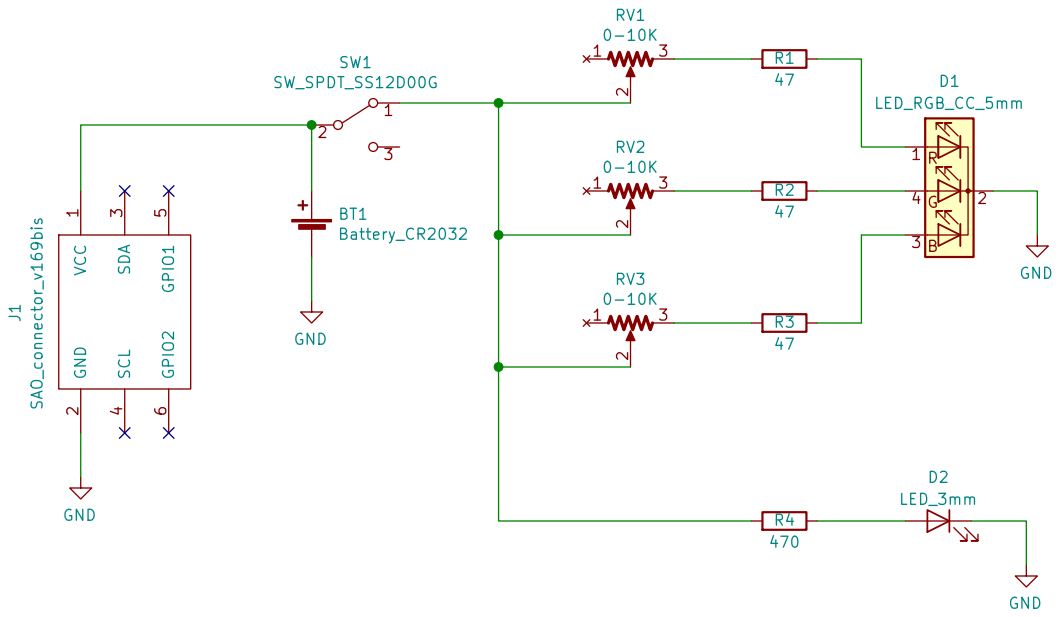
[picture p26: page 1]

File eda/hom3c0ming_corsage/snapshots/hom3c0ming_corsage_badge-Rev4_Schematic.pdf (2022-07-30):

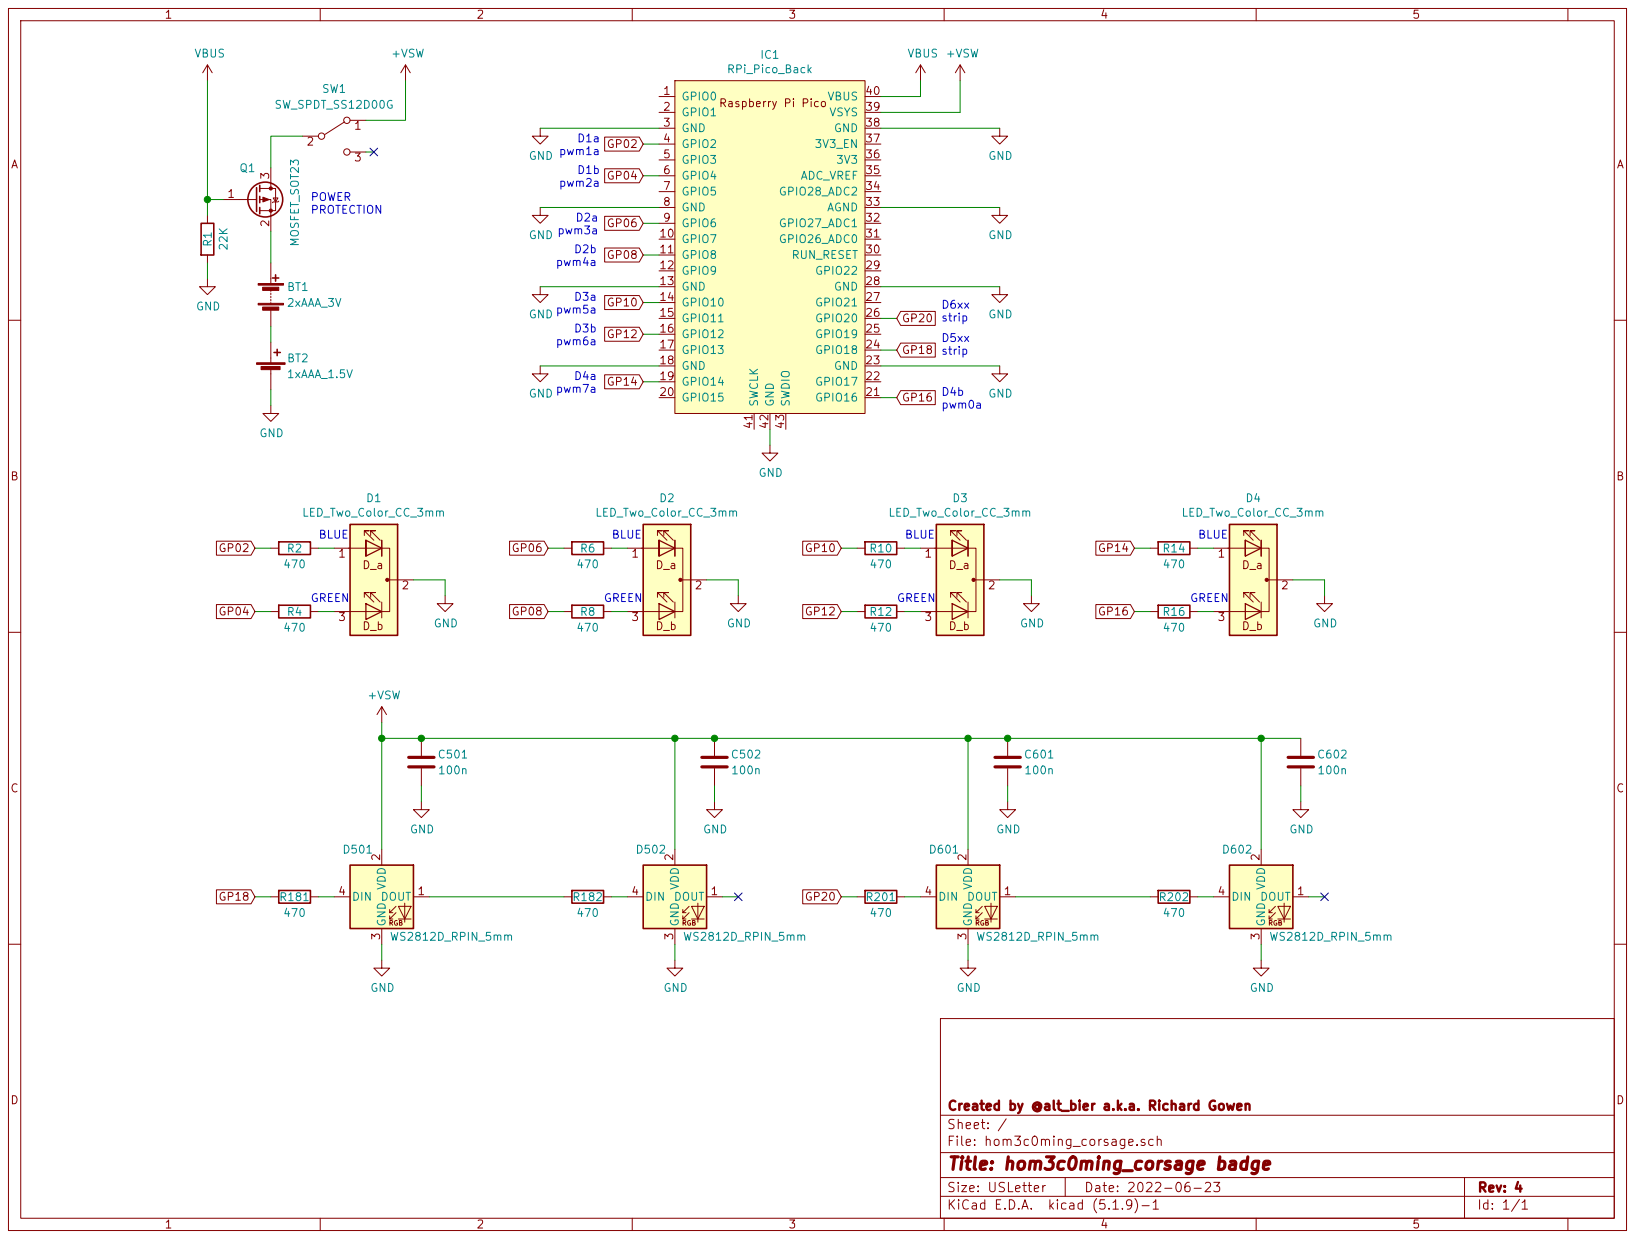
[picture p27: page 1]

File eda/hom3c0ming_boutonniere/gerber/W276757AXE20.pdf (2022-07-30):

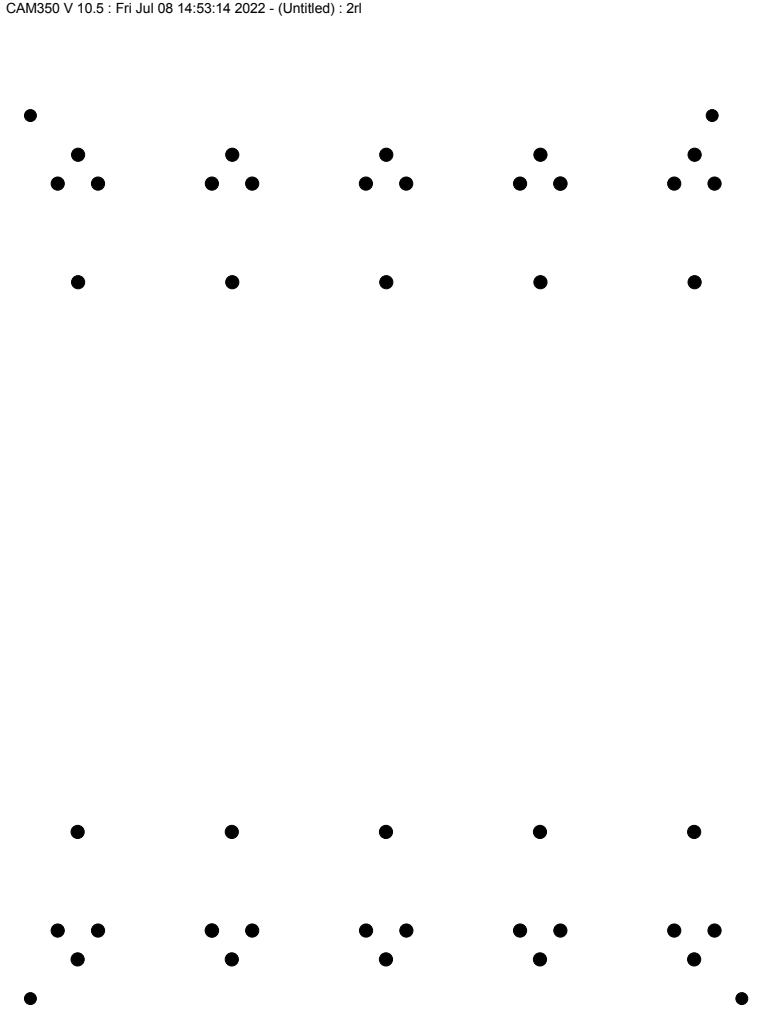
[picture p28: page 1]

CAM350 V 10.5 : Fri Jul 08 14:53:14 2022 - (Untitled) : 2rl

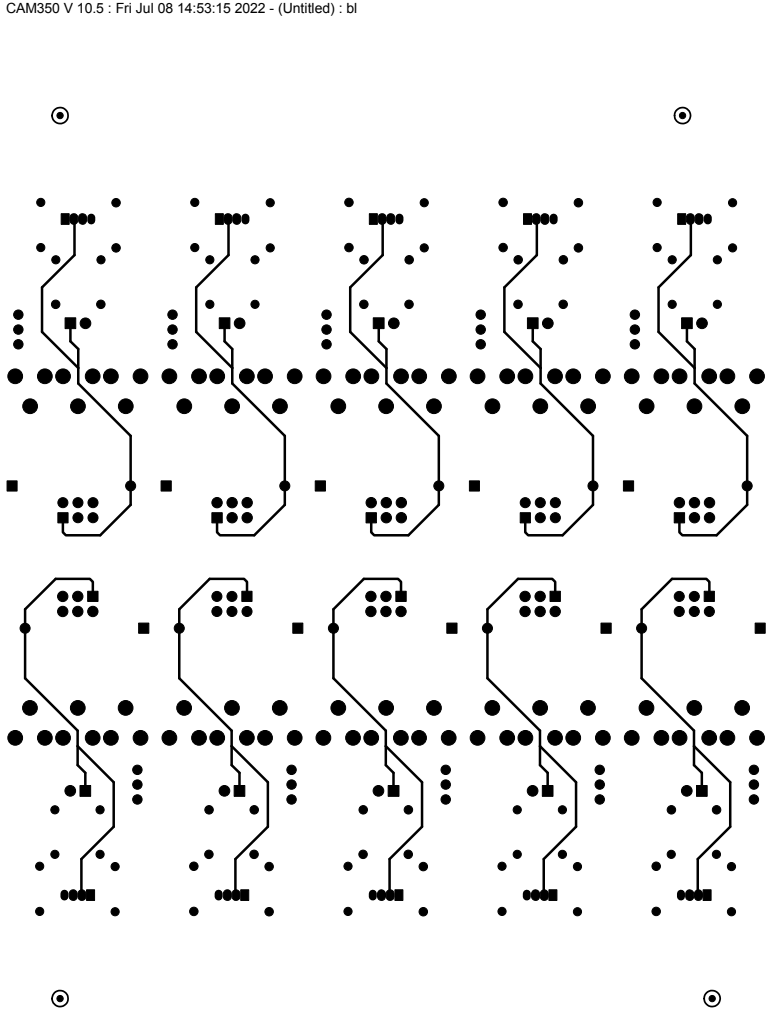
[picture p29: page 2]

CAM350 V 10.5 : Fri Jul 08 14:53:15 2022 - (Untitled) : bl

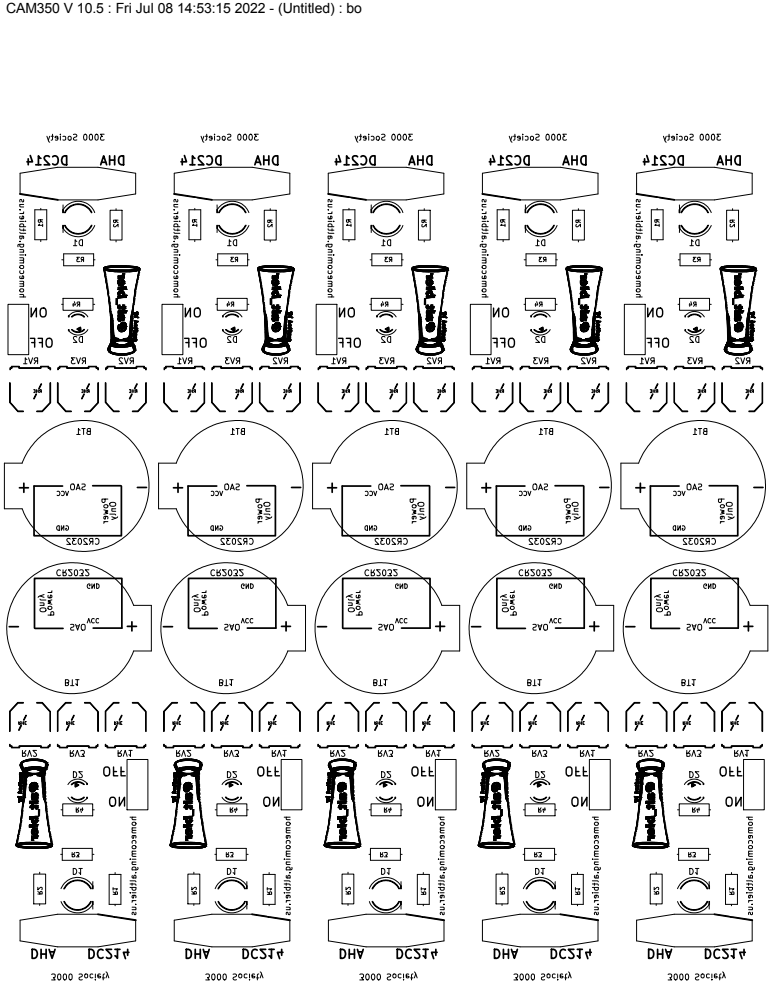
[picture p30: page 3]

CAM350 V 10.5 : Fri Jul 08 14:53:15 2022 - (Untitled) : bo

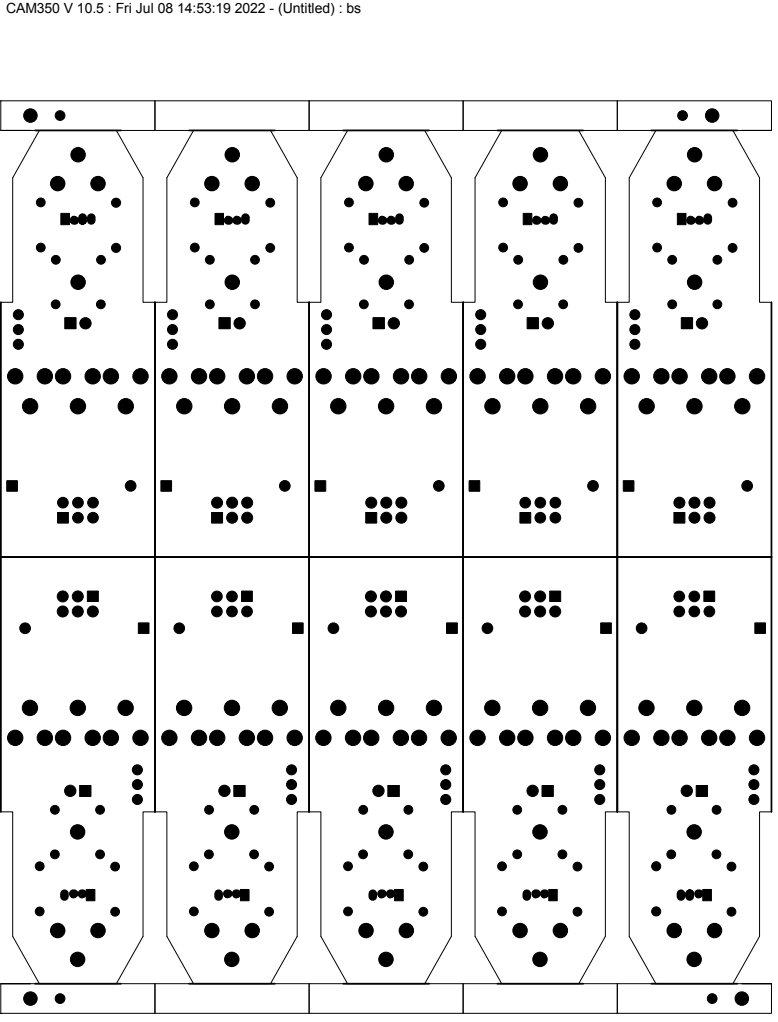
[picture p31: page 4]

CAM350 V 10.5 : Fri Jul 08 14:53:19 2022 - (Untitled) : bs

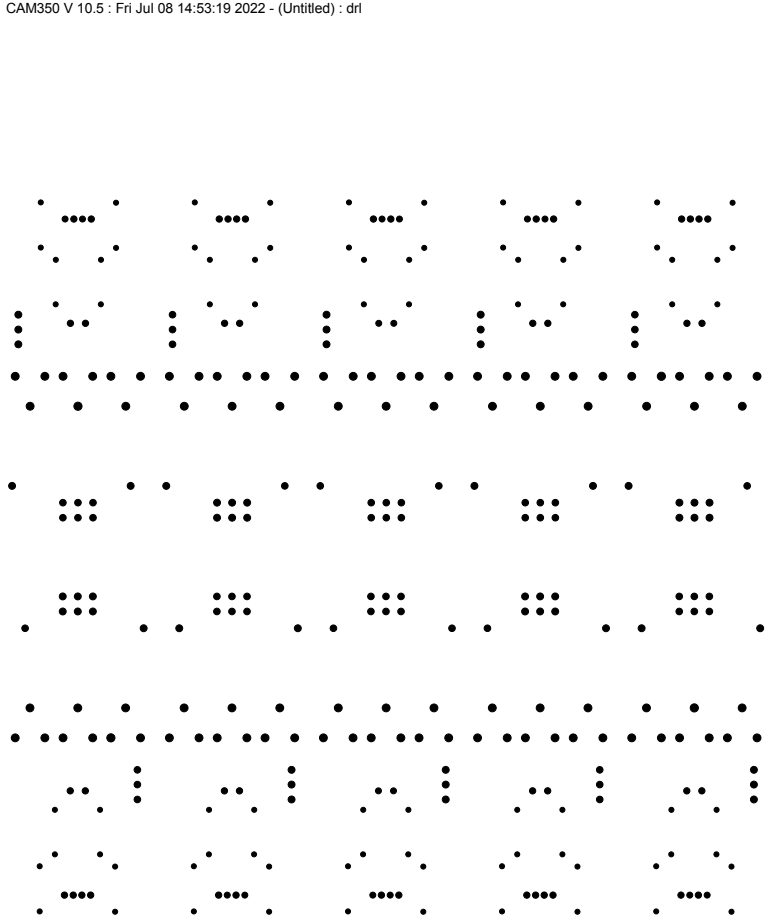
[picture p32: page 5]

CAM350 V 10.5 : Fri Jul 08 14:53:19 2022 - (Untitled) : drl

CAM350 V 10.5 : Fri Jul 08 14:53:19 2022 - (Untitled) : ko

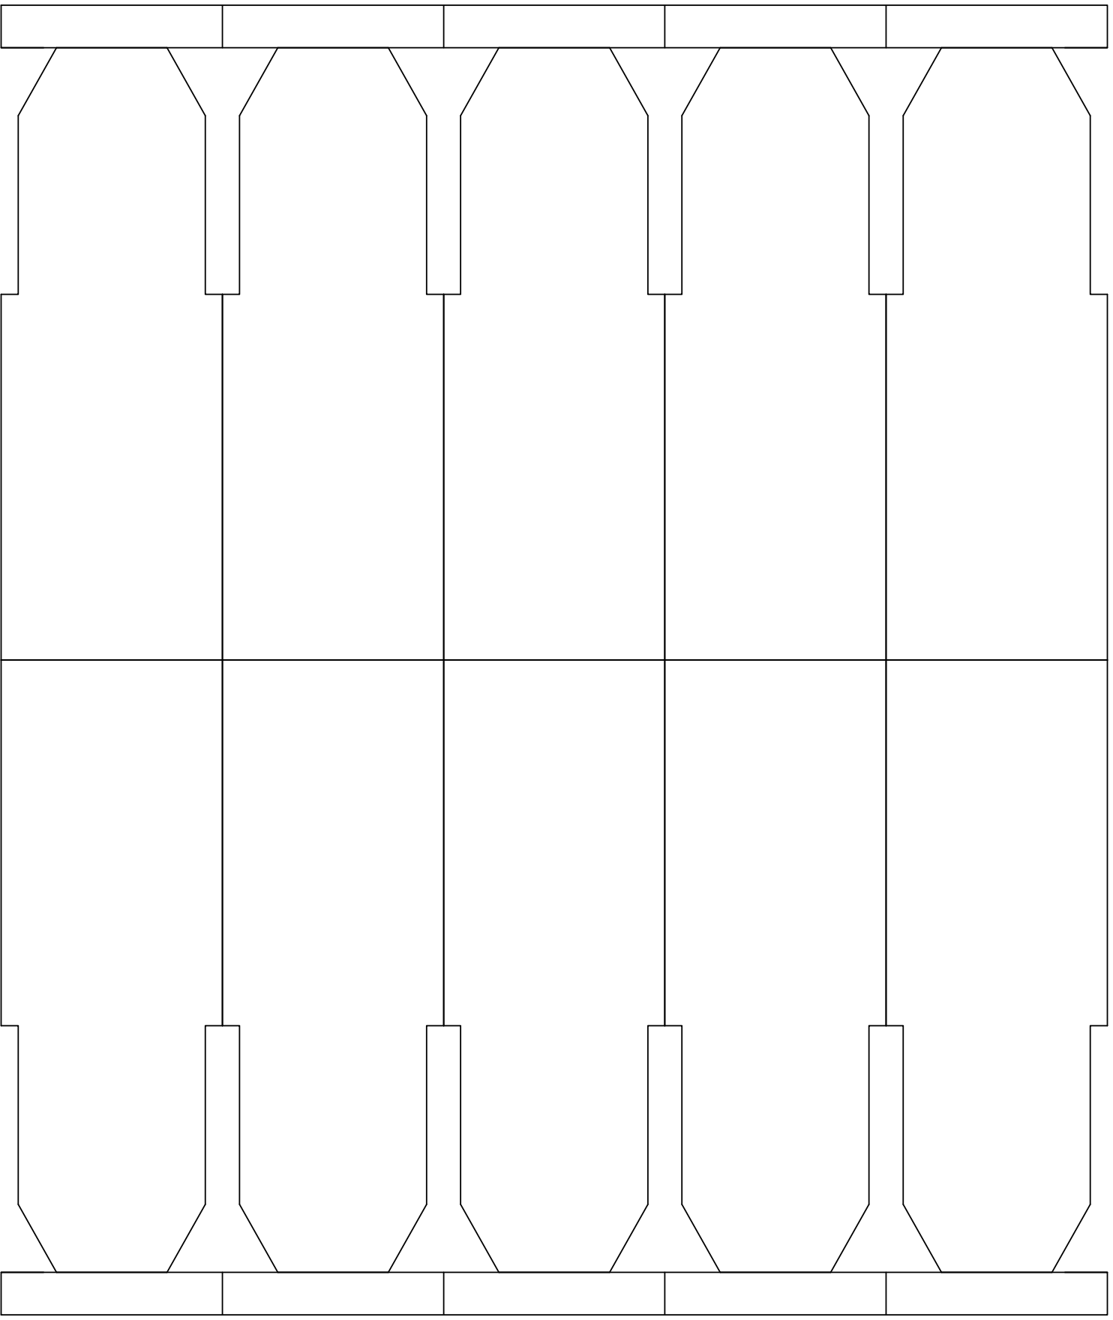
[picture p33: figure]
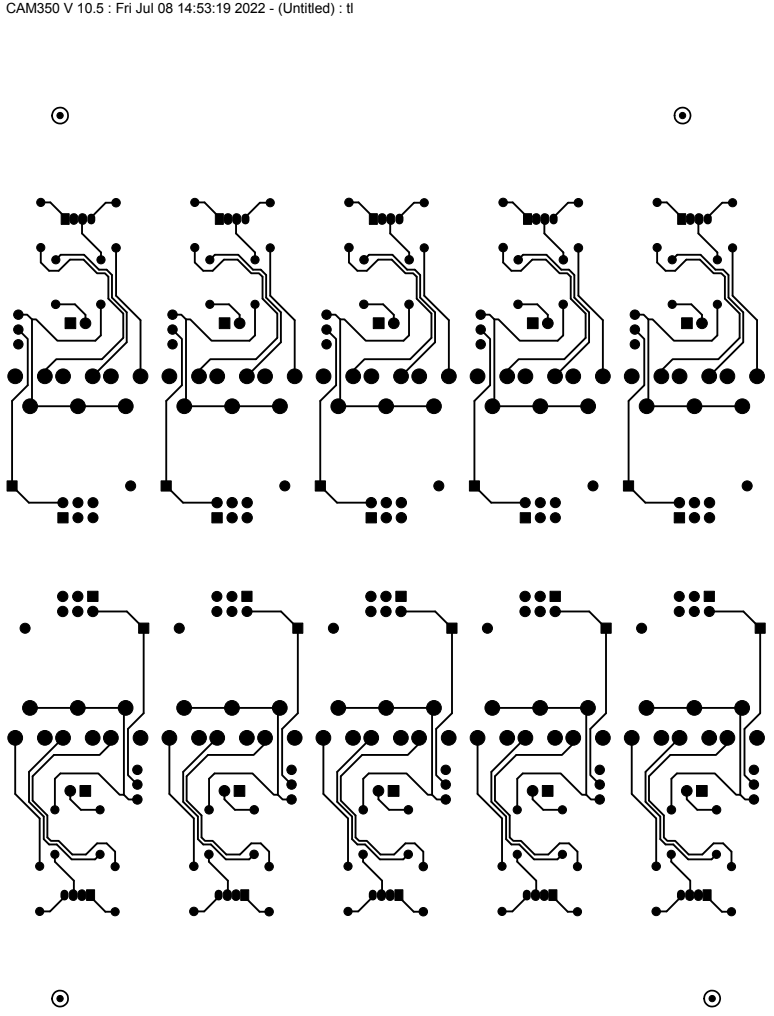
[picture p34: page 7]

CAM350 V 10.5 : Fri Jul 08 14:53:19 2022 - (Untitled) : tl

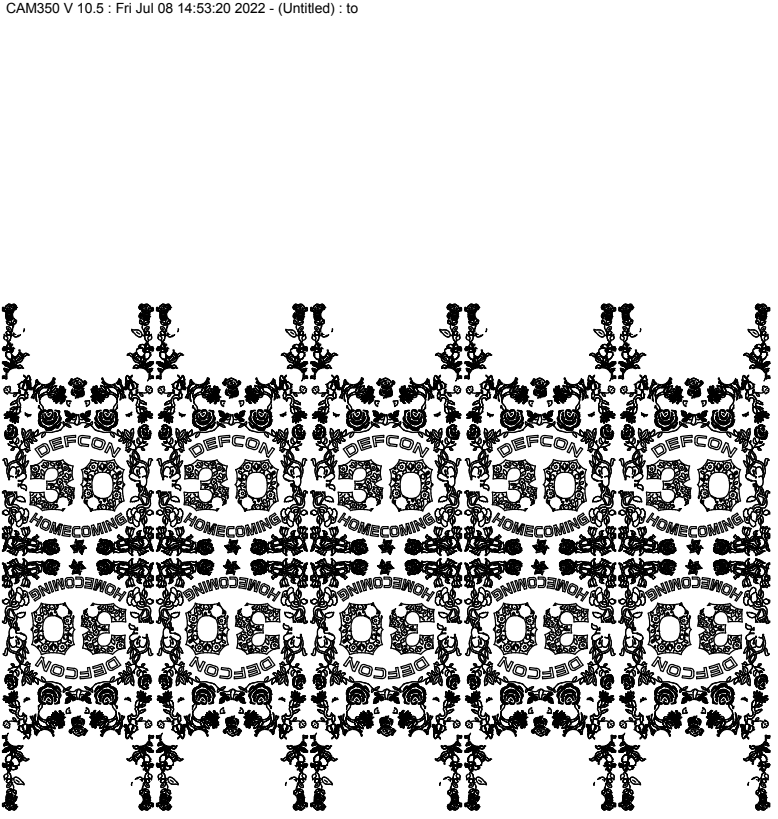
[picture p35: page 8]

CAM350 V 10.5 : Fri Jul 08 14:53:20 2022 - (Untitled) : to

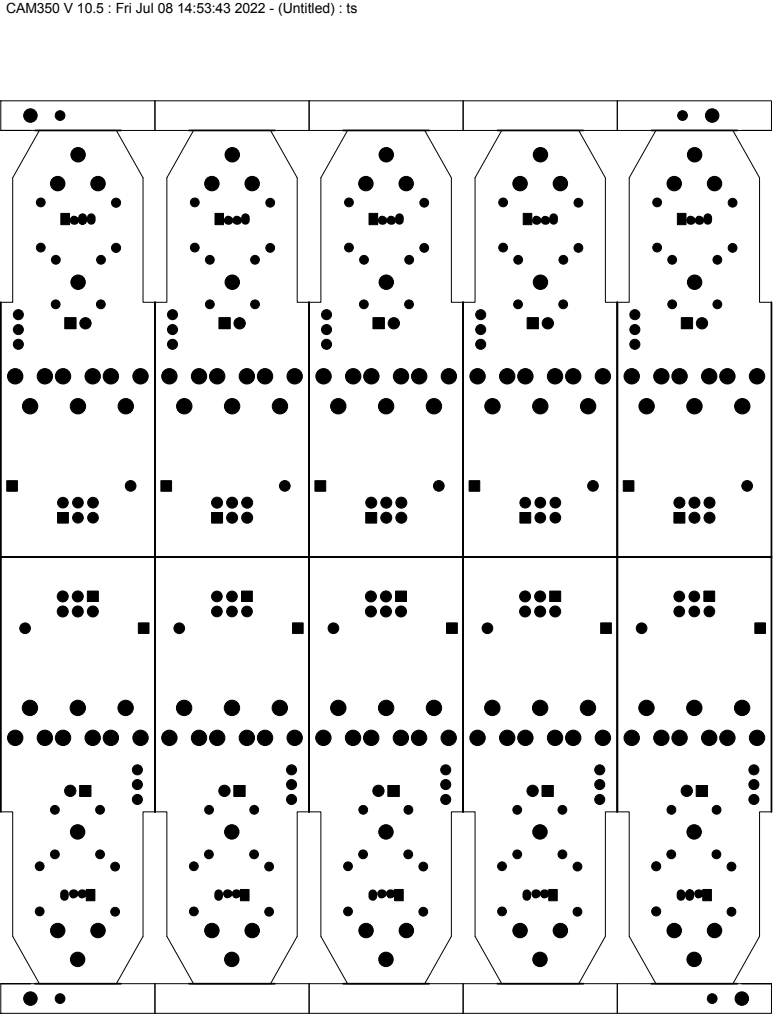
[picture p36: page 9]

CAM350 V 10.5 : Fri Jul 08 14:53:43 2022 - (Untitled) : ts

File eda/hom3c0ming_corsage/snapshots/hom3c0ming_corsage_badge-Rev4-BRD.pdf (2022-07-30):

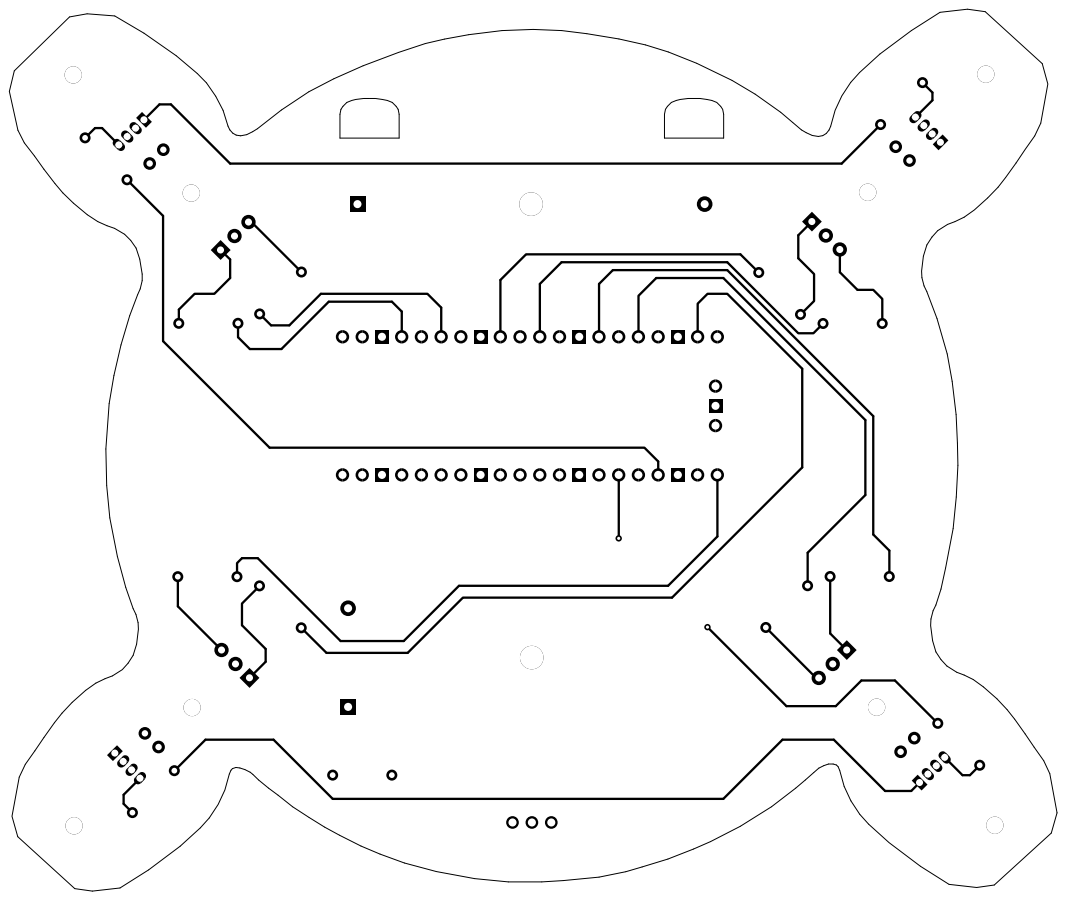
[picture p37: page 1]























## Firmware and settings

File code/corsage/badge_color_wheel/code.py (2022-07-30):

import board
import digitalio
import time
import neopixel
import pwmio

# On board LED
led = digitalio.DigitalInOut(board.LED)
led.direction = digitalio.Direction.OUTPUT

# WS2812D Reversed Pin 'NeoPixel' LEDs
# Note: NeoPixel Values specified as (G, R, B)

# NeoPixel strip connected on GP18
NUMPIXELSGP18 = 2
neopixelsgp18 = neopixel.NeoPixel(board.GP18, NUMPIXELSGP18, brightness=0.5, auto_write=False)

# NeoPixel strip connected on GP20
NUMPIXELSGP20 = 2
neopixelsgp20 = neopixel.NeoPixel(board.GP20, NUMPIXELSGP20, brightness=0.5, auto_write=False)

# Blue/Green Common Cathode LED
d1blu = pwmio.PWMOut(board.GP2, frequency=5000, duty_cycle=0)
d1grn = pwmio.PWMOut(board.GP4, frequency=5000, duty_cycle=0)
d2blu = pwmio.PWMOut(board.GP6, frequency=5000, duty_cycle=0)
d2grn = pwmio.PWMOut(board.GP8, frequency=5000, duty_cycle=0)
d3blu = pwmio.PWMOut(board.GP10, frequency=5000, duty_cycle=0)
d3grn = pwmio.PWMOut(board.GP12, frequency=5000, duty_cycle=0)
d4blu = pwmio.PWMOut(board.GP14, frequency=5000, duty_cycle=0)
d4grn = pwmio.PWMOut(board.GP16, frequency=5000, duty_cycle=0)

# Function to give us a nice color swirl on NeoPixel (G,R,B)
def wheeln(pos, sft):
    # pos = position, sft = shift-position
    #
    # Want a minimum of red since these are flowers
    redmin = 30
    if (pos + sft) > 255:
        pos = (pos + sft) - 256
    else:
        pos = (pos + sft)
    if (pos < 0) or (pos > 255):
        return (0, 0, 0)
    if pos < 85:
        return (int(pos*3), int(max(redmin, (255 - pos*3))), 0)
    elif pos < 170:
        pos -= 85
        return (int(255 - (pos*3)), redmin, int(pos*3))
    else:
        pos -= 170
        return (0, int(max(redmin, (pos*3))), int(255 - pos*3))

# Function to turn on/off led
def leaf(pos, sft, brt, min):
    # pos = position, sft = shift-position, brt = brightness (0.1-1.0), min = minimum
    #
    # Set maximum leaf brightness
    # Full=65535 Half=32768 Quarter=16384
    # Setting to Full-value * brightness-value
    leafhigh = 65535 * brt
    if (pos + sft) > 255:
        pos = (pos + sft) - 256
    else:
        pos = (pos + sft)
    if (pos) < 128:
        leafstate = int(max(min, (pos * 2 * leafhigh / 255)))
    else:
        leafstate = int(max(min, (leafhigh - int((pos - 128) * 2 * leafhigh / 255))))
    return leafstate

# Function to turn all LEDs off in a neopixel string
def alloff(pixel):
    for j in range(len(pixel)):
        pixel[j] = (0, 0, 0)

######################### MAIN LOOP ##############################
i = 0
alloff(neopixelsgp18)
alloff(neopixelsgp20)
while True:
    led.value = 1
    #
    # D501
    neopixelsgp18[0] = wheeln(i, 0)
    # D502
    neopixelsgp18[1] = wheeln(i, 32)
    # D601
    neopixelsgp20[0] = wheeln(i, 64)
    # D602
    neopixelsgp20[1] = wheeln(i, 96)
    #
    neopixelsgp18.show()
    neopixelsgp20.show()
    #
    d1grn.duty_cycle = leaf(i, 0, 0.6, 6554)
    d1blu.duty_cycle = leaf(i, 32, 0.4, 0)
    d2grn.duty_cycle = leaf(i, 32, 0.6, 6554)
    d2blu.duty_cycle = leaf(i, 64, 0.4, 0)
    d3grn.duty_cycle = leaf(i, 64, 0.6, 6554)
    d3blu.duty_cycle = leaf(i, 96, 0.4, 0)
    d4grn.duty_cycle = leaf(i, 96, 0.6, 6554)
    d4blu.duty_cycle = leaf(i, 128, 0.4, 0)
    #
    print("i: ", i, " d1grn: ", d1grn.duty_cycle, " d1blu: ", d1blu.duty_cycle, " d501(G,R,B): ", neopixelsgp18[0])
    #
    i = (i+1) % 256
    #
    time.sleep(0.02) # make bigger to slow down

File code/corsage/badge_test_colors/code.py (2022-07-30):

import board
import digitalio
import time
import neopixel
import pwmio

# On board LED
led = digitalio.DigitalInOut(board.LED)
led.direction = digitalio.Direction.OUTPUT

# WS2812D Reversed Pin 'NeoPixel' LEDs
# Note: NeoPixel Values specified as (G, R, B)

# NeoPixel strip connected on GP18
NUMPIXELSGP18 = 2
neopixelsgp18 = neopixel.NeoPixel(board.GP18, NUMPIXELSGP18, brightness=1, auto_write=False)

# NeoPixel strip connected on GP20
NUMPIXELSGP20 = 2
neopixelsgp20 = neopixel.NeoPixel(board.GP20, NUMPIXELSGP20, brightness=1, auto_write=False)

# Blue/Green Common Cathode LED
d1blu = digitalio.DigitalInOut(board.GP2)
d1blu.direction = digitalio.Direction.OUTPUT
d1grn = digitalio.DigitalInOut(board.GP4)
d1grn.direction = digitalio.Direction.OUTPUT
d2blu = digitalio.DigitalInOut(board.GP6)
d2blu.direction = digitalio.Direction.OUTPUT
d2grn = digitalio.DigitalInOut(board.GP8)
d2grn.direction = digitalio.Direction.OUTPUT
d3blu = digitalio.DigitalInOut(board.GP10)
d3blu.direction = digitalio.Direction.OUTPUT
d3grn = digitalio.DigitalInOut(board.GP12)
d3grn.direction = digitalio.Direction.OUTPUT
d4blu = digitalio.DigitalInOut(board.GP14)
d4blu.direction = digitalio.Direction.OUTPUT
d4grn = digitalio.DigitalInOut(board.GP16)
d4grn.direction = digitalio.Direction.OUTPUT

# Function to turn all LEDs off in a neopixel string
def alloff(pixel):
    for j in range(len(pixel)):
        pixel[j] = (0, 0, 0)

######################### MAIN LOOP ##############################
i = 0
alloff(neopixelsgp18)
alloff(neopixelsgp20)
while True:
    led.value = 1
    # ########## RED ##########
    # GRB
    neopixelsgp18[0] = (0, 255, 0)
    neopixelsgp18[1] = (0, 255, 0)
    neopixelsgp20[0] = (0, 255, 0)
    neopixelsgp20[1] = (0, 255, 0)
    #
    neopixelsgp18.show()
    neopixelsgp20.show()
    #
    d1grn.value = 0
    d1blu.value = 0
    d2grn.value = 0
    d2blu.value = 0
    d3grn.value = 0
    d3blu.value = 0
    d4grn.value = 0
    d4blu.value = 0
    #
    time.sleep(0.5)
    #
    # ########## GRN ##########
    # GRB
    neopixelsgp18[0] = (255, 0, 0)
    neopixelsgp18[1] = (255, 0, 0)
    neopixelsgp20[0] = (255, 0, 0)
    neopixelsgp20[1] = (255, 0, 0)
    #
    neopixelsgp18.show()
    neopixelsgp20.show()
    #
    d1grn.value = 1
    d1blu.value = 0
    d2grn.value = 1
    d2blu.value = 0
    d3grn.value = 1
    d3blu.value = 0
    d4grn.value = 1
    d4blu.value = 0
    #
    time.sleep(0.5)
    #
    # ########## BLU ##########
    # GRB
    neopixelsgp18[0] = (0, 0, 255)
    neopixelsgp18[1] = (0, 0, 255)
    neopixelsgp20[0] = (0, 0, 255)
    neopixelsgp20[1] = (0, 0, 255)
    #
    neopixelsgp18.show()
    neopixelsgp20.show()
    #
    d1grn.value = 0
    d1blu.value = 1
    d2grn.value = 0
    d2blu.value = 1
    d3grn.value = 0
    d3blu.value = 1
    d4grn.value = 0
    d4blu.value = 1
    #
    time.sleep(0.5)
    #

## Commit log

2022-06-06 Updates to 3D print files
    [Rose_LED_Cover_w_Leaves.3mf, Rose_LED_Cover_w_Leaves.stl]
2022-07-30 Code merge from private repo
    [BatteryHolder_2466_1xAAA.step, BatteryHolder_2468_2xAAA.step, Battery_Holder_3xAAA_Simple.step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]

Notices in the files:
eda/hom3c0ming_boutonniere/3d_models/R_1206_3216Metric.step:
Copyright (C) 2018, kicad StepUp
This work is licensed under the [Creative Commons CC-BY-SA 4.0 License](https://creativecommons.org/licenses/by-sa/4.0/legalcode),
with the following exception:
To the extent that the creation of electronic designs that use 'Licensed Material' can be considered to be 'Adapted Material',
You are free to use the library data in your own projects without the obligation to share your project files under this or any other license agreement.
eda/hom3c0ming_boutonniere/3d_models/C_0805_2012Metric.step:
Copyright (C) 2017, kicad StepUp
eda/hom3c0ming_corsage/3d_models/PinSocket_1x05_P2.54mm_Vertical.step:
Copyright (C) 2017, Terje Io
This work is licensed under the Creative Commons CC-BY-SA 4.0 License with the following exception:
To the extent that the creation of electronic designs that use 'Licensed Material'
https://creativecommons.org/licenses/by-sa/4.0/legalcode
